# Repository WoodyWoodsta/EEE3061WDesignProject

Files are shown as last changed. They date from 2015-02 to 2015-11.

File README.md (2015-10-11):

# EEE3061W Mechatronics Design Project

Both single-thread and RTOS projects as well as other goodies for the biathletic robot as part of the Mechatronics Design project. 

*Includes:*
- 1st Semester C Project (Single thread)
- 2nd Semester C Project (FreeRTOS + CMSIS RTOS API + STM32Cube)
- All Altium Schematics and PCB Layouts
- Latex code for all reports

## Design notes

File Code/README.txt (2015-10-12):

The code included in this submission contains the following:

- "Team13 - 1stSemester.zip"
  - 1st semester code, single threaded, all main execution in main.c with calls to supporting libraries included.
  - Makes use of the Standard Peripheral Library supplied by ST Microelectronics

- "Team13 - 2ndSemester.zip"
  - 2nd semester code, multi-threaded, threads and queues are created in main.c as well as the kernel is fired in main()
  - Thread source is named "*_task.c"
  - Makes use of FreeRTOS V8.2.1, CMSIS RTOS API, CMSIS Hardware Abstraction Layer and originates from STM32CubeMX using their libraries

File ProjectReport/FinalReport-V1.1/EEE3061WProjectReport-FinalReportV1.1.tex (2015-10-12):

\input{woodamble}                                                       % Custom preamble
%----------------------------------------------------------------------------------------
% NAME AND CLASS SECTION
%----------------------------------------------------------------------------------------

\newcommand{\reportTitle}{Final Report} % Assignment title
\newcommand{\reportDueDate}{Wednesday,\ September\ 03,\ 2014}                    % Due date
\newcommand{\reportClass}{EEE3061W - Mechatronics Design}                               % Course/class
\newcommand{\reportClassTime}{10:30am}                                 % Class/lecture time
\newcommand{\reportClassInstructor}{Jones}                               % Teacher/lecturer
\newcommand{\reportAuthorName}{Team 13}                           % Your name
\newcommand{\reportDepartment}{Department of Electrical Engineering}           % Department

%----------------------------------------------------------------------------------------
% TITLE PAGE
%----------------------------------------------------------------------------------------

\title{
\begin{figure}[H]
  \begin{center}
    
  \end{center}
\end{figure}
\textmd{\Huge UNIVERSITY OF CAPE TOWN \\ \LARGE \reportDepartment} \\
\vspace{2in}
\textmd{\textbf{\LARGE \reportClass \\ \Huge Biathlon Robot \\ \reportTitle \\ \vspace{1.5in} \Large Team 13 \\  WDXSEA003 \textbar\space PRSSAM004 \textbar\space RJDYAR001 \textbar\space STRIBR001}}\\
}

\date{}

%========================================================================================
%========================================================================================

\begin{document}
  \maketitle
  \thispagestyle{empty}

\frontmatter
%----------------------------------------------------------------------------------------
% ABTRACT
%----------------------------------------------------------------------------------------
\setcounter{tocdepth}{3}                                                      % ToC Depth
\setcounter{secnumdepth}{2}                                     % Section Numbering Depth

\clearpage
\section*{Plaigiarism Declaration}
\addcontentsline{toc}{section}{Plaigiarism Declaration}
\label{sec:Plaigiarism Declaration}

\clearpage
\begin{figure}[H]
  \begin{center}
    
  \end{center}
\end{figure}

\begin{figure}[H]
  \begin{center}
    
  \end{center}
\end{figure}

\begin{abstract}
  \thispagestyle{empty}
  This report covers the post-design commentary and as-built designs of an autonomous bi-athletic robot for the EEE3061W Mechatronics Design Project 2015.  This robot was to partake in a sprint as well as launch a ping-pong ball after tracking a line and being aware of the end of the course. Most of the specifications were met and the robot performed the tasks that were set out at the beginning of the project.

\end{abstract}

%----------------------------------------------------------------------------------------
% TABLE OF CONTENTS
%----------------------------------------------------------------------------------------

\cleardoublepage
\addcontentsline{toc}{section}{Table of Contents}
\tableofcontents

\clearpage
\section*{List of Illustrations}
\addcontentsline{toc}{section}{List of Illustrations}
\label{sec:List of Illustrations}
\addcontentsline{toc}{subsection}{List of Figures}
\listoffigures
\clearpage

%----------------------------------------------------------------------------------------
% GLOSSARY
%----------------------------------------------------------------------------------------

%----------------------------------------------------------------------------------------
% INTRODUCTION
%----------------------------------------------------------------------------------------
\mainmatter
\clearpage
\section{Introduction}
\label{sec:Introduction}
  This report covers post-testing commentary and as-built designs for EEE3061W Mechatronics Design Project for 2015.  The project involved the design, manufacture and testing of a legged, autonomous, bi-athletic robot that was be able to partake in a 5m sprint, follow a line then throw a ping-pong ball.  The robot was to adhere to a set of specifications as provided by the course management. \\

  The entire project was split into two sections, each covering the semester's task.  The first section involved the sprinting aspect of the robot, and the second involved line following and launching.

  \subsection{Sprinter Introduction}
  \label{sub:Sprinter Introduction}
    In summary, the sprinting robot was to make use of a digital 3-axis gyroscope in an attempt to sprint 5m as fast as possible within a f ixed-width lane (maintain fixed heading).  The robot was also specified to start the sprint when the green light from a set of three lights was detected, signaling the beginning of the race. \\

    The locomotion design was constrained to the use of legs, making use of a mechanical linkage-type system to convert rotational motion from the provided motors into linear motion to move forward.  Other restrictions included the dimensions of the entire robot and out-of-pocket components budget.

  \subsection{Launcher Introduction}
  \label{sub:Launcher Introduction}
    The second stage of the project required the robot to first navigate along a line (autonomously) into a box and then throw a ping-pong ball as far as possible. The launching mechanism was limited to the use of a lever system, driven by a DC motor provided.  The rest of the restrictions follow from the Sprinter as well. \\

  The development of both robots followed the same design process whereby 3 conceptual designs were proposed and one final design (or a combination of ideas from more than one) was developed upon further after having drawn up a pros and cons comparison.  The final design was, at this stage, separated into the electronic and mechanical aspects.  As such, they are discussed separately.  Mechanical designs were modelled using SolidWorks and the electronic systems were drawn up in Altium Designer.

%----------------------------------------------------------------------------------------
% ELECTRICAL COMMENTARY
%----------------------------------------------------------------------------------------
\clearpage
\section{Electrical Commentary}
\label{sec:Electrical Commentary}
  Electrical systems for both semester's worth of design were on Printed Circuit Boards (PCBs), the first semester's PCBs being manufactured using the ``press-n-peel'' method and the second semester PCBs being manufactured professionally at Trax\footnote{Trax PCB Manufacture - \url{http://www.trax.co.za/}}. Both systems worked successfully after manufacture and minimal changes were made to the PCBs for the final demonstrations of the robot. Commentary on both systems and the associated software that was written for the systems can be found below.

  \subsection{Electrical System Design}
  \label{sub:Electrical System Design}
    \subsubsection{PCB Manufacturing Process}
    \label{subs:PCB Manufacturing Process}
      As stated, the PCBs manufactured for the first semester's robot were made using copper clad board and ``press-n-peel'' paper. This constrained the design of the boards since the manufacturing process was much more error prone. The track width minimum was increased greatly, decreasing the allowable complexity of the board layout thus increasing the overall size. Using this method also meant that the boards could not be double sided, further decreasing the complexity given the size.\\

      The second semester saw the PCBs manufactured professionally at Trax. This allowed a much smaller minimum track width and clearance limit (0.254mm) and could be manufactured double-sided with vias as well as a silk screen and solder mask. This gave the boards a much more professional feel, with easier assembly due to the silk screen and solder mask.

    \subsubsection{Power Supply Toplogy}
    \label{subs:Power Supply Toplogy}
      The addition of far more functionality in the second semester system meant the system drew a significantly larger amount of current excluding that of the motors. This saw the 12-5V regulation phase (LM317) dissipating a very large amount of heat, which is characteristic of linear voltage regulators operating at the level experienced. Use of a switched mode power supply would have reduced the power dissipation and minimised the need for a heat sink which took up an unnecessary amount of space on the final system.

    \subsubsection{Surface Mount Components}
    \label{subs:Surface Mount Components}
      The second semester system used surface mount forms of most of the passive electrical components in the system which had a huge impact on the final size of the boards. This was made possible by the professional manufacture process. The STM32F051C6 remained as a pluggable daughter board with two rows of headers. The STM32F0 could have been soldered directly to the main ControllerBoard which would have saved a lot of space, at least vertically.

  \subsection{Software Design}
  \label{sub:Software Design}
    \subsubsection{Software Structure}
    \label{subs:Software Structure}
      All software was written in C for the STM32F051C6. The software system written for the 1st semester robot was single-threaded and made use of a ``super-loop'' type layout, where initialisations were performed at the beginning and the main execution looped through in one loop with calls to various custom written libraries throughout. This suited the task as the level of complexity was not high, however, many parts of the super-loop became unused as the sequence progressed (such as checking for the green light).\\

      A more advanced method of scheduling was used in the second semester system to better suit the multi-functional nature of the newer system. The FreeRTOS\textsuperscript{\cite{freeRTOS}} kernel was implemented to bring to the system the ability to split the program into multiple threads (or tasks) which minimised the scheduling implications of a super-loop style program. Calls to the FreeRTOS source base were made using the CMSIS RTOS API specially written for the STM range of microcontrollers which worked well except for having to manually implement some unfinished feature inclusions in the API.\\

      The GitHub Repository used throughout the project can be found at \url{https://github.com/WoodyWoodsta/EEE3061WDesignProject/tree/master/Code}.

    \subsubsection{Control Methodology}
    \label{subs:Control Methodology}
      For both maintaining a fixed heading and line following, the control loop types were intended to be PID and this type of control was implemented fully in both software systems. However, in both cases, the system to control turned out to be too complex to model and thus only the proportional component of the control loops were used. This sufficed for both the straight line test as well as following a curved line with the sensors.

%----------------------------------------------------------------------------------------
% MECHANICAL COMMENTARY
%----------------------------------------------------------------------------------------
\clearpage
\section{Mechanical Commentary}
\label{sec:Mechanical Commentary}
The mechanical design consisted mainly of the leg mechanism attached to a generic base and later a launcher was added to the center. The mechanism chosen for the legs was based off a Klann linkage\textsuperscript{\cite{klannLinkage}} which is common amongst walking robots. The mechanism converts rotary motion to linear motion which replicates moving legs. The primary difficulty with this mechanism was the non-fluid motion of the Klann linkage design. With regards to the first semester design, these limitations meant high stress concentrations were created at critical points within the linkage. As a result, the central leg linkage was fractured during testing. Other complications with the design centered on the high friction generated between moving parts. This was partly due to the choice of material but mostly as a result of the small scale of the robot relative to the external and internal forces generated.\\

Apart from this, the rest of the robot functioned relatively well from the first iteration. The calculated gear ratio was accurate because the required torque needed to overcome the weight of the robot was reached from the first design.\\

\subsection{Linkage Size and Strength}
\label{sub:Linkage Size and Strength}
  From the post design work it was apparent that the linkage size, particularly around the interfaces with other links was insufficient in the first design. We also learnt that having moving parts made of Perspex in direct contact with each other was conducive to high friction generation. As well as this, despite the gears functioning appropriately, there was significant difficulty in locating the gears. In the first design, Perspex was attached using epoxy perpendicularly to the Perspex base. This interface had to be reattached multiple times as the material used was not ideal for epoxy attachments.\\

  To address the main problem of linkage fracture, the size of each linkage interface as well as the linkages themselves was increased. This was done to rectify any stress concentrations that may have developed during usage due to misalignment. Additionally, the carbon fiber rods were replaced with standard nuts and bolts in all shaft requirements. The friction generated within linkages due to the carbon fiber rods resulted in the degradation of the holes within linkages which contributed significantly to the misalignment problem. To further alleviate this problem, brass bushings were placed in every hole within the Perspex. To assist with the gear location, hex shaped holes were cut into the Perspex and a hex nut was force fit into it. This allowed the gear to be threaded onto the bar easily, and could be kept in place using lock nuts. Between each of the linkages, a stationary Perspex spacer was placed to prevent direct contact between them. This not only significantly reduced the friction but also assisted in maintaining linkage alignment.\\

\subsection{Body Size}
\label{sub:Body Size}
  The overall size of the robot was increased to accommodate the launcher mechanism. This was necessary to ensure optimal functionality and performance of both the launcher and the leg mechanism. Worm gears were included in the leg mechanism due to the increased weight of the robot and therefore the increased need for more torque. The compromise was that the overall speed of the robot was heavily sacrificed.

%----------------------------------------------------------------------------------------
% RESULTS AND CONCLUSIONS
%----------------------------------------------------------------------------------------
\clearpage
\section{Results and Conclusions}
\label{sec:Results and Conclusions}
  \subsection{Sprinter Results}
  \label{sub:Sprinter Results}
    The robot built for the 1st semester demonstration was able to remain within the demarcated track width autonomously and do so at a reasonable pace. The robot successfully completed the race after sensing the green light in variable ambient conditions.\\

    Apart from a fractured leg that occurred during the demonstrations, the robot was able to continue to perform.

  \subsection{Launcher Results}
  \label{sub:Launcher Results}
    The robot built for the 2nd semester demonstration was able to start following the line after the light was sensed and the line following was very successful. It achieved this autonomously and was able to sense the box marking on the floor and move into the box. The robot was then able to throw the ping pong ball after reaching the edge of the box to complete the task.

%----------------------------------------------------------------------------------------
% BIBLIOGRAPHY
%----------------------------------------------------------------------------------------
\clearpage
% \nocite{*}
\printbibliography

%----------------------------------------------------------------------------------------
% APPENDICES
%----------------------------------------------------------------------------------------
\section{APPENDIX A: Final Electrical Schematics}
\label{sec:APPENDIX A: Final Electrical Schematics}
  \subsection{1st Semester Electrical Schematics}
  \label{sub:1st Semester Electrical Schematics}

    \begin{figure}[H]
      \begin{center}
        \makebox[\textwidth][c]{}
        \caption{Schematic of the PowerBoard in the 1st Semester Electrical System}
        \label{fig:PowerBoardSchematic}
      \end{center}
    \end{figure}

    \begin{figure}[H]
      \begin{center}
        \makebox[\textwidth][c]{}
        \caption{Schematic of the ControllerBoard in the 1st Semester Electrical System}
        \label{fig:ControllerBoardSchematic}
      \end{center}
    \end{figure}

  \subsection{2nd Semester Electrical Schematics}
  \label{sub:2nd Semester Electrical Schematics}

    \begin{figure}[H]
      \begin{center}
        \makebox[\textwidth][c]{}
        \caption{Schematic of the PowerBoard in the 2nd Semester Electrical System}
        \label{fig:PowerBoardSchematicV2}
      \end{center}
    \end{figure}

    \begin{figure}[H]
      \begin{center}
        \makebox[\textwidth][c]{}
        \caption{Schematic of the ControllerBoard in the 2nd Semester Electrical System}
        \label{fig:ControllerBoardV2Schematic}
      \end{center}
    \end{figure}

    \begin{figure}[H]
      \begin{center}
        \makebox[\textwidth][c]{}
        \caption{Schematic of the SensorBoard in the 2nd Semester Electrical System}
        \label{fig:LineSensorBoardSchematic}
      \end{center}
    \end{figure}

    \begin{figure}[H]
      \begin{center}
        
        \caption{Schematic of the SensorModule in the 2nd Semester Electrical System}
        \label{fig:LineSensorModuleSchematic}
      \end{center}
    \end{figure}

\clearpage
\section{APPENDIX B: Final Electrical PCB Designs}
\label{sec:APPENDIX B: Final Electrical PCB Designs}
  \subsection{1st Semester Electrical PCB Designs}
  \label{sub:1st Semester Electrical PCB Designs}

    \begin{figure}[H]
      \begin{center}
        \makebox[\textwidth][c]{}
        \caption{PCB Layout of the PowerBoard in the 1st Semester Electrical System}
        \label{fig:PowerBoardPCBRev1}
      \end{center}
    \end{figure}

    \begin{figure}[H]
      \begin{center}
        \makebox[\textwidth][c]{}
        \caption{PCB Layout of the ControllerBoard in the 1st Semester Electrical System}
        \label{fig:ControllerBoardPCB}
      \end{center}
    \end{figure}

  \subsection{2nd Semester Electrical PCB Designs}
  \label{sub:2nd Semester Electrical PCB Designs}

    \begin{figure}[H]
      \begin{center}
        \makebox[\textwidth][c]{}
        \caption{PCB Layout of the PowerBoard in the 2nd Semester Electrical System}
        \label{fig:PowerBoardPCBV2}
      \end{center}
    \end{figure}

    \begin{figure}[H]
      \begin{center}
        \makebox[\textwidth][c]{}
        \caption{PCB Layout of the ControllerBoard in the 2nd Semester Electrical System}
        \label{fig:ControllerBoardV2PCB}
      \end{center}
    \end{figure}

    \begin{figure}[H]
      \begin{center}
        \makebox[\textwidth][c]{}
        \caption{PCB Layout of the SensorBoard in the 2nd Semester Electrical System}
        \label{fig:LineSensorBoardPCBRev2}
      \end{center}
    \end{figure}

    \begin{figure}[H]
      \begin{center}
        \makebox[\textwidth][c]{}
        \caption{PCB Layout of the SensorModule in the 2nd Semester Electrical System}
        \label{fig:SensorModulePCB}
      \end{center}
    \end{figure}

\clearpage
\section{APPENDIX C: Final Mechanical Drawings}
\label{sec:APPENDIX C: Final Mechanical Drawings}

\end{document}
%----------------------------------------------------------------------------------------
% INSTRUCTIONS AND TEMPLATE COMPONENTS
%----------------------------------------------------------------------------------------

% Set space - \vspace{length}
% Horizontal line - \hrule
% Pagebreak - \clearpage or \newpage - they seem to do the same thing

% Normal equation:
% \begin{equation}
%   p = \frac{p_g - k}{m}
% \end{equation}

% Aligned equation:
% \begin{equation}
%   \begin{split}
%     \rho_5  & = -\frac{\left(1575-1900\right)}{g\left(105\e{-3}-70\e{-3}\right)}\\
%             & = 946.56 \text{ kg/m\(^{-3}\)}\\
%     \rho_6  & = -\frac{\left(1900-2150\right)}{g\left(70\e{-3}-42\e{-3}\right)}\\
%             & = 910.15 \text{ kg/m\(^{-3}\)}\\
%   \end{split}
% \end{equation}

% Table: Can get from the table site!
% \begin{table}[h]
% \centering
% \begin{tabular}{cccc}
% \multicolumn{4}{c}{\cellcolor[HTML]{EFEFEF}DATA MEASUREMENTS} \\ \hline
% \multicolumn{1}{c|}{\begin{tabular}[c]{@{}c@{}}Known Weight \\ Pressure (Psi)\end{tabular}} & \multicolumn{1}{c|}{\begin{tabular}[c]{@{}c@{}}Known Weight\\ Pressure (Bar)\end{tabular}} & \multicolumn{1}{c|}{\begin{tabular}[c]{@{}c@{}}Gauge Pressure\\ (Psi)\end{tabular}} & \begin{tabular}[c]{@{}c@{}}Gauge Pressure\\ (Bar)\end{tabular} \\ \hline
% \multicolumn{1}{c|}{22} & \multicolumn{1}{c|}{1.52} & \multicolumn{1}{c|}{9.43} & 0.65 \\
% \multicolumn{1}{c|}{\textbf{27}} & \multicolumn{1}{c|}{\textbf{1.86}} & \multicolumn{1}{c|}{\textbf{13.78}} & \textbf{0.95} \\
% \multicolumn{1}{c|}{32} & \multicolumn{1}{c|}{2.21} & \multicolumn{1}{c|}{17.40} & 1.20 \\
% \multicolumn{1}{c|}{37} & \multicolumn{1}{c|}{2.55} & \multicolumn{1}{c|}{21.76} & 1.50 \\
% \multicolumn{1}{c|}{42} & \multicolumn{1}{c|}{2.90} & \multicolumn{1}{c|}{26.11} & 1.80 \\
% \multicolumn{1}{c|}{47} & \multicolumn{1}{c|}{3.24} & \multicolumn{1}{c|}{29.01} & 2.00 \\
% \multicolumn{1}{c|}{\textbf{52}} & \multicolumn{1}{c|}{\textbf{3.59}} & \multicolumn{1}{c|}{\textbf{33.36}} & \textbf{2.30} \\
% \multicolumn{1}{c|}{57} & \multicolumn{1}{c|}{3.93} & \multicolumn{1}{c|}{37.71} & 2.60 \\ \hline
% \end{tabular}
% \caption{Dead weight tester and gauge measurements}
% \label{gaugeMeasurements}
% \end{table}

% Picture:
% \begin{figure}[H]
%   \begin{center}
%     \includegraphics[width=0.4\columnwidth]{MEC2022SLab1Exp1}
%     \caption{Apparatus}
%     \label{liquidDiagram}
%   \end{center}
% \end{figure}

% Graph:
% \begin{figure}[H]
%   \centering
%   \begin{tikzpicture}
%     \begin{axis}[
%       xlabel=Known Weight (Psi),
%       ylabel=Reading (Psi),
%       grid=major]
%     \addplot[color=red, smooth] coordinates {
%       (22,9.43)
%       (27,13.78)
%     };
%     \addlegendentry{Gauge}

%     \addplot[color=blue, dashed, smooth] coordinates {
%       (22,22)
%       (27,27)
%     };
%     \addlegendentry{Known weight}

%     \end{axis}
%   \end{tikzpicture}
%   \caption{Dead weight tester and gauge measurements}
%   \label{gaugePlot}
% \end{figure}

% Indented Text: (bit of a hacky way to do it)
% \begin{quote}
% where \(p_g\) is the gauge reading, \(m\) is the error coefficient, \(p\) is the known (``correct'') pressure and \(k\) is the error constant
% \end{quote}

% Code Snippet:
% \begin{minted}{c}
%   void main(void) {
%     init_leds();
%
%     while (TRUE) {
%       __asm("nop");
%     }
%   }
% \end{minted}

% Bibliography:
% \begin{thebibliography}{99}
%   \bibitem{itemname}
%   Author,
%   Date.
%   \emph{Title}.
%   Edition.
%   Press.
%   \url{http://web.iitd.ac.in/~shouri/eel201/tuts/diode_switch.pdf}
% \end{thebibliography}

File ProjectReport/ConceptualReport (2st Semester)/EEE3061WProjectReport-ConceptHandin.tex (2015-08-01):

\input{woodamble}                                                       % Custom preamble
%----------------------------------------------------------------------------------------
% NAME AND CLASS SECTION
%----------------------------------------------------------------------------------------

\newcommand{\hmwkTitle}{Conceptual Design Report} % Assignment title
\newcommand{\hmwkDueDate}{Wednesday,\ September\ 03,\ 2014}                    % Due date
\newcommand{\hmwkClass}{EEE3061W - Mechatronics Design}                    % Course/class
\newcommand{\hmwkClassTime}{10:30am}                                 % Class/lecture time
\newcommand{\hmwkClassInstructor}{Jones}                               % Teacher/lecturer
\newcommand{\hmwkAuthorName}{Team 13}    % Your name
\newcommand{\hmwkDepartment}{Department of Electrical Engineering}           % Department

%----------------------------------------------------------------------------------------
% TITLE PAGE
%----------------------------------------------------------------------------------------

\title{
\begin{figure}[H]
  \begin{center}
    
  \end{center}
\end{figure}
\textmd{\Huge UNIVERSITY OF CAPETOWN \\ \LARGE \hmwkDepartment} \\
\vspace{2in}
\textmd{\textbf{\LARGE \hmwkClass \\ \Huge Biathlon Robot \\ \hmwkTitle \\ \vspace{1.5in} \Large Team 13 \\  WDXSEA003 \textbar\space PRSSAM004 \textbar\space RJDYAR001 \textbar\space STRIBR001}}\\
%\normalsize\vspace{0.1in}\small{Due\ on\ \hmwkDueDate}\\
%\vspace{0.1in}\large{\textit{\hmwkClassInstructor\ \hmwkClassTime}}
}

\date{}

%========================================================================================
%========================================================================================

\begin{document}

\maketitle
\clearpage

%----------------------------------------------------------------------------------------
% ABTRACT
%----------------------------------------------------------------------------------------
\setcounter{tocdepth}{2}                                                      % ToC Depth

% \begin{abstract}
% This preliminary report covers the conceptual design stage of the EEE3061W Mechatronics Design 2015 project involving the design and manufacture of a bi-athletic robot.  This robot is to partake in a sprint as well as throw a weighted ping-pong ball.

% \end{abstract}
% \newpage

%----------------------------------------------------------------------------------------
% TABLE OF CONTENTS
%----------------------------------------------------------------------------------------

% \clearpage

% \tableofcontents

% \clearpage

% \listoffigures
% \listoftables

% \clearpage

% %----------------------------------------------------------------------------------------
% % NOMENCLATURE
% %----------------------------------------------------------------------------------------

% \begin{homeworkProblem}[{Nomenclature}]
% \textbf{Constants}

% \(V_{LINE}\) - Nominal Line Voltage\\
% \(A_v\) - Operational Amplifier Gain\\
% \(db_{SPL}\) - Sound Pressure Level\\
% \(\theta_S\) - Phase Shift

% \end{homeworkProblem}

%----------------------------------------------------------------------------------------
% INTRODUCTION
%----------------------------------------------------------------------------------------
\begin{homeworkProblem}[{Introduction}]
This preliminary report and reports hereafter together cover the complete design process for EEE3061W Mechatronics Design Project for 2015.  The project involves the design, manufacture and testing of a legged, autonomous, bi-athletic robot that will be able to partake in a 5m sprint and then throw a weighted ping-pong ball.  The robot is to adhere to a set of specifications as provided by the course management. \\

The following report details the concepts and designs for the second stage of the project, namely the shotput challenge. In this stage, the primary requirements are for the robot to launch a ping pong ball as perpendicularly far as possible. The launcher should be attached to the same robot as the previous project. As well as this, the launcher should be self-reloadable and utilise the power of the given DC motor to achieve launching.

\begin{homeworkSection}{Aim}
To assess and compare conceptual designs of robot launchers and conclude which is the most feasible and viable for this application.
\end{homeworkSection}

\begin{homeworkSection}{Method}
  \begin{itemize}
    \item Generate designs
    \item Detail and explain each concept
    \item Compare and contrast each design
    \item Decide on a final concept design
    \item Generate conclusions based on the chosen design
  \end{itemize}
\end{homeworkSection}
\end{homeworkProblem}

%----------------------------------------------------------------------------------------
% DESIGN CONCEPTS
%----------------------------------------------------------------------------------------
\begin{homeworkProblem}[{Design Concepts}]
\begin{homeworkSection}{Design Concept 1}
  \begin{figure}[H]
    \begin{center}
      
      \caption{3D Render of Design Concept 1}
      \label{concept1}
    \end{center}
  \end{figure}

The first design is clearly based on a standard catapult. This is the first concept chosen as it is the simplest and most common design. The function of the catapult is based loosely on a mousetrap and employs the same general idea of the trap's spring loaded release mechanism. The difference is that there is a stopper mid-way through the movement of the catapult arm which allows for a short impulse time during the release of the ping pong ball. For the reload mechanism, the motor is used to wind back the catapult arm until it hits a mechanical latch. This is achieved by the use of a high step down gearbox to generate enough torque in order to extend the springs. Once the the catapult is in position and the ball is placed on the launcher, the mechanical latch will then be released electronically which will then activate the catapult mechanism. \\

Another possibility, which can be applied to all the subsequent designs in addition to this one, is to have the reload mechanism only activate once the ball is in the holder. This removes the need to have time delay between the reload and launch sequence, and reduces the overall amount of mechanisms and moving parts. This vould be achieved by using a light sensor to sense when the ball is in holder while it is in the upright position.
\end{homeworkSection}

\begin{homeworkSection}{Design Concept 2}
  \begin{figure}[H]
    \begin{center}
      
      \caption{3D Render of Design Concept 2}
      \label{concept2}
    \end{center}
  \end{figure}

For this concept, a similar mechanism is used as in the previous one, but instead of a catapult - type launcher, it utilises a more direct “hit” impact on the ball. this is more in line with the nature of springy ping pong balls' projection. Similar to the previous concept, the lever arm is pulled back by using the motor and a series of gears. This is again held in place by a mechanical latch and is released again once a light sensor is triggered within the tube holder. The ball sits in the holder with approximately half of the ball jutting out where the paddle will hit the ball. The impact allows for a very short impulse time and a fast projection of the ping pong ball.

\end{homeworkSection}

\begin{homeworkSection}{Design Concept 3}
  \begin{figure}[H]
    \begin{center}
      
      \caption{3D Render of Design Concept 3}
      \label{concept3}
    \end{center}
  \end{figure}

  The third and final concept design is based on a ballista/crossbow design. This allows for a potentially more stable arrangement as the only moving parts are the spring devices or elastic cables. this means there are no rigid components that have to move, which will reduce any uncertainty. The basic design uses a winch that pulls back the elastic band using the motor. A similar latch system is then used which will ultimately launch the ping pong ball. The motor ultimately engages and disengages the the latch and a light sensor will again detect the ball and trigger the motor to disengage the latch.

\end{homeworkSection}
\end{homeworkProblem}

\clearpage

\begin{homeworkProblem}[{Final Concept}]
\begin{table}[H]
\centering
\caption{Design Concept Comparison Table}
\label{comparisonTable}
\begin{tabular}{@{}cccccc@{}}
\toprule
\multicolumn{2}{c}{{\bf Design 1}} & \multicolumn{2}{c}{{\bf Design 2}} & \multicolumn{2}{c}{{\bf Design 3}} \\ \midrule
{\bf Pros} & {\bf Cons} & {\bf Pros} & {\bf Cons} & {\bf Pros} & {\bf Cons} \\
\begin{tabular}[c]{@{}c@{}}Simplest \\ mechanism\end{tabular} & \begin{tabular}[c]{@{}c@{}}May not be \\ suitable for \\ this projectile\end{tabular} & \begin{tabular}[c]{@{}c@{}}Relatively\\ simple\\ mechanism\end{tabular} & \begin{tabular}[c]{@{}c@{}}Difficult to\\ control\end{tabular} & \begin{tabular}[c]{@{}c@{}}Most stable\\ design\end{tabular} & \begin{tabular}[c]{@{}c@{}}May not be\\ suitable for this\\ projectile\end{tabular} \\
\begin{tabular}[c]{@{}c@{}}Ease of\\ assembly\end{tabular} & \begin{tabular}[c]{@{}c@{}}Relatively\\ large\end{tabular} & \begin{tabular}[c]{@{}c@{}}Ease of\\ assembly\end{tabular} & \begin{tabular}[c]{@{}c@{}}Relatively\\ large\end{tabular} & \begin{tabular}[c]{@{}c@{}}Smallest\\ in size\end{tabular} & \begin{tabular}[c]{@{}c@{}}Difficult to\\ assemble\end{tabular} \\
\begin{tabular}[c]{@{}c@{}}Uses\\ standard\\ parts\end{tabular} & \begin{tabular}[c]{@{}c@{}}Could\\ damage robot\\ due to sudden\\ stopping\end{tabular} & \begin{tabular}[c]{@{}c@{}}Uses\\ standard\\ parts\end{tabular} & \begin{tabular}[c]{@{}c@{}}Could damage\\ robot due to\\ impact stopping\end{tabular} & \begin{tabular}[c]{@{}c@{}}Sudden impact\\ would not\\ affect robot\end{tabular} & \begin{tabular}[c]{@{}c@{}}Some parts\\ may be\\ difficult to\\ create\end{tabular} \\ \bottomrule
\end{tabular}
\end{table}

After considering the above table and other factors, Design concept 2 was chosen as the final concept. The deciding factor was that for a ball of this size, weight and springy nature, a sudden impact or hit imparted on the ball would be able to project the ball the furthest distance.

\begin{homeworkSection}{Other Design Considerations and Potential Improvements}

Although the current chosen design is simple, adding some degree of complexity could improve the overall performance. In particular, the use of a solenoid instead of a mechanical release would make the launch far more consistent and easier to time and predict (however, this is not a possibility due to project criteria and restrictions). \\

From the above SolidWorks models, there is much to improve on in terms of sizing. These steps however can be taken further down the iterative optimisation path. The choice of material may also change as more convenient and less costly options are possibly discovered.
\end{homeworkSection}

\end{homeworkProblem}

%----------------------------------------------------------------------------------------
% PRELIMINARY CALCULATIONS
%----------------------------------------------------------------------------------------
\begin{homeworkProblem}[{Preliminary Calculations}]
  \begin{table}[H]
\centering
\caption{Table of Constants}
\label{constantsTable}
\begin{tabular}{|l|l|}
\hline
Coefficient of restitution (\(e\)) & 0.90                \\ \hline
Mass of table tennis ball (\(m_1\))  & 2.7 g               \\ \hline
Voltage of motor (\(V\))           & 12 V                \\ \hline
Current of motor (\(A\))           & 0.1 A               \\ \hline
Angle of launch (\(\theta\))            & 45 degrees          \\ \hline
Drag coefficient (\(Cd\))           & 0.5                 \\ \hline
Density of air (\(\rho\))             & 1.274 kg/m\(^3\) \\ \hline
Diameter of ball (\(d\))           & 40 mm               \\ \hline
Mass of lever arm (\(m_2\))          & 17 g                \\ \hline
Spring constant (\(k\))               & 3.45 N              \\ \hline
Lever arm length (\(L\))           & 100 mm              \\ \hline
\end{tabular}
\end{table}

\textbf{Assumptions Made:}
\begin{itemize}
  \item From extensive research the torque required to put a mousetrap spring down by 60 degrees is 0.212 Nm.
  \item The height of the robot is ignored in distance calculations as it is only 150 mm of the ground.
\end{itemize}

\textbf{Torque Required:}
\begin{equation}
  \begin{split}
    T &= 0.212 \text{Nm}\\
    P &= VI = (12)(0.1)\\
    P &= 1.2 \text{W}\\
    P &= \omega T\\
    \omega &= \frac{P}{T}\\
    \omega &= 5.66 \text{ rad}^{-1}\\
    \omega &= 612.61 \text{ rad}^{-1} \text{Output from motor at 12 V}\\
    \text{motor step} &= \frac{612.61}{5.66} = 108
  \end{split}
\end{equation}

This step can be achieved using a worm gear combined with a gear train.\\

\textbf{Speed of ping pong ball:}

Energy conservation:

\begin{equation}
  U = V + E_k + E_p
\end{equation}

\begin{equation}
  \frac{k\theta^2}{2} = \frac{I\omega^2}{2} + \frac{m(\omega r)^2}{2} + mgh
\end{equation}
\begin{equation}
  \frac{3.45(1.04)^2}{2} = \frac{(1.67 \e{-9})\omega^2}{2} + \frac{0.017(\omega \times 0.1)^2}{2} + 0.017(9.81)(0.1)
\end{equation}
\begin{equation}
  1.89 - 0.0167 = 8.87 \e{-5} \omega^2
\end{equation}
\begin{equation}
  \omega = 145.36 \text{ rad}^{-1}
\end{equation}
\begin{equation}
  v = \omega r = 14.5 \text{m/s}^{-1}
\end{equation}
\begin{equation}
  e m_1 v_1 = m_2 v_2
\end{equation}
\begin{equation}
  v_2 = \frac{17}{2.7} \times 14.5 \times 0.90
\end{equation}
\begin{equation}
  v_2 = 85.77 \text{m/s}^{-1}
\end{equation}

From dynamic calculations, given the launch angle and using an online ping pong ball calculator, the distance found was \textbf{21.4368 m}.

\begin{figure}[H]
  \begin{center}
    
    \caption{Ball Speed Calculator}
    \label{ballspeed}
  \end{center}
\end{figure}

\end{homeworkProblem}

\end{document}
%----------------------------------------------------------------------------------------
% INSTRUCTIONS AND TEMPLATE COMPONENTS
%----------------------------------------------------------------------------------------

% Document is structured in --> [document]
%                                 [homeworkProblem]
%                                   [homeworkSection]
%                                     [COMPONENTS]

% Set space - \vspace{length}
% Horizontal line - \hrule
% Pagebreak - \clearpage or \newpage - they seem to do the same thing

% Normal equation:
% \begin{equation}
%   p = \frac{p_g - k}{m}
% \end{equation}

% Aligned equation:
% \begin{equation}
%   \begin{split}
%     \rho_5  & = -\frac{\left(1575-1900\right)}{g\left(105\e{-3}-70\e{-3}\right)}\\
%             & = 946.56 \text{ kg/m\(^{-3}\)}\\
%     \rho_6  & = -\frac{\left(1900-2150\right)}{g\left(70\e{-3}-42\e{-3}\right)}\\
%             & = 910.15 \text{ kg/m\(^{-3}\)}\\
%   \end{split}
% \end{equation}

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

% Picture:
% \begin{figure}[H]
%   \begin{center}
%     \includegraphics[width=0.4\columnwidth]{MEC2022SLab1Exp1}
%     \caption{Apparatus}
%     \label{liquidDiagram}
%   \end{center}
% \end{figure}

% Graph:
% \begin{figure}[H]
%   \centering
%   \begin{tikzpicture}
%     \begin{axis}[
%       xlabel=Known Weight (Psi),
%       ylabel=Reading (Psi),
%       grid=major]
%     \addplot[color=red, smooth] coordinates {
%       (22,9.43)
%       (27,13.78)
%     };
%     \addlegendentry{Gauge}

%     \addplot[color=blue, dashed, smooth] coordinates {
%       (22,22)
%       (27,27)
%     };
%     \addlegendentry{Known weight}

%     \end{axis}
%   \end{tikzpicture}
%   \caption{Dead weight tester and gauge measurements}
%   \label{gaugePlot}
% \end{figure}

% Indented Text: (bit of a hacky way to do it)
% \begin{quote}
% where \(p_g\) is the gauge reading, \(m\) is the error coefficient, \(p\) is the known (``correct'') pressure and \(k\) is the error constant
% \end{quote}

% Code Snippet:
% \begin{lstlisting}
% .model AKM02 D(Is=1.5n Rs=.5 Cjo=80p M=0.3 Vj=1 nbv=3 bv=6.2 Ibv=1m Vpk=6.2 mfg=OnSemi type=zener)
% \end{lstlisting}

% Bibliography:
% \begin{thebibliography}{99}
%   \bibitem{itemname}
%   Author,
%   Date.
%   \emph{Title}.
%   Edition.
%   Press.
%   \url{http://web.iitd.ac.in/~shouri/eel201/tuts/diode_switch.pdf}
% \end{thebibliography}

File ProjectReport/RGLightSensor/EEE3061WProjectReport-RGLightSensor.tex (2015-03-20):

\input{woodamble}                                                       % Custom preamble
%----------------------------------------------------------------------------------------
% NAME AND CLASS SECTION
%----------------------------------------------------------------------------------------

\newcommand{\hmwkTitle}{RG Light Sensor Report} % Assignment title
\newcommand{\hmwkDueDate}{Wednesday,\ September\ 03,\ 2014}                    % Due date
\newcommand{\hmwkClass}{EEE3061W - Mechatronics Design}                    % Course/class
\newcommand{\hmwkClassTime}{10:30am}                                 % Class/lecture time
\newcommand{\hmwkClassInstructor}{Jones}                               % Teacher/lecturer
\newcommand{\hmwkAuthorName}{Team 13}    % Your name
\newcommand{\hmwkDepartment}{Department of Electrical Engineering}           % Department

%----------------------------------------------------------------------------------------
% TITLE PAGE
%----------------------------------------------------------------------------------------

\title{
\begin{figure}[H]
  \begin{center}
    
  \end{center}
\end{figure}
\textmd{\Huge UNIVERSITY OF CAPETOWN \\ \LARGE \hmwkDepartment} \\
\vspace{2in}
\textmd{\textbf{\LARGE \hmwkClass \\ \Huge Biathlon Robot \\ \hmwkTitle \\ \vspace{1.5in} \Large Team 13 \\  WDXSEA003 \textbar\space PRSSAM004 \textbar\space RJDYAR001 \textbar\space STRIBR001}}\\
%\normalsize\vspace{0.1in}\small{Due\ on\ \hmwkDueDate}\\
%\vspace{0.1in}\large{\textit{\hmwkClassInstructor\ \hmwkClassTime}}
}

\date{}

%========================================================================================
%========================================================================================

\begin{document}

\maketitle
\clearpage

%----------------------------------------------------------------------------------------
% ABTRACT
%----------------------------------------------------------------------------------------
\setcounter{tocdepth}{2}                                                      % ToC Depth

% \begin{abstract}
% This preliminary report covers the conceptual design stage of the EEE3061W Mechatronics Design 2015 project involving the design and manufacture of a bi-athletic robot.  This robot is to partake in a sprint as well as throw a weighted ping-pong ball.

% \end{abstract}
% \newpage

%----------------------------------------------------------------------------------------
% TABLE OF CONTENTS
%----------------------------------------------------------------------------------------

% \clearpage

% \tableofcontents

% \clearpage

% \listoffigures
% \listoftables

% \clearpage

%----------------------------------------------------------------------------------------
% NOMENCLATURE
%----------------------------------------------------------------------------------------

%----------------------------------------------------------------------------------------
% INTRODUCTION
%----------------------------------------------------------------------------------------
\begin{homeworkProblem}[{Introduction}]
This report covers the design and build of an Red\(\slash\)Green Light Detecting Sensor (hereafter referred to as RG Sensor) as part of the EEE3061W Mechatronics Design Project involving the building of a biathletic robot.
\end{homeworkProblem}

%----------------------------------------------------------------------------------------
% CIRCUIT DIAGRAM
%----------------------------------------------------------------------------------------
\begin{homeworkProblem}[Circuit Diagram]
Figure \ref{schematic1} shows the complete circuit diagram for the light sensor including the sensing, ambient sensing, indication and digital output portions of the circuit.

\begin{figure}[H]
  \begin{center}
    
    \caption{Complete circuit diagram of the RG Light Sensor}
    \label{schematic1}
  \end{center}
\end{figure}

\end{homeworkProblem}

%----------------------------------------------------------------------------------------
% CIRCUIT DIAGRAM
%----------------------------------------------------------------------------------------
\begin{homeworkProblem}[Brief Explanation and Calculations]
The team took on a slightly unorthodox approach to sensing the different coloured sources of light in that the sensing is performed by LEDs themselves.  The LM358N is set up in a comparator configuration, one for sensing red light and the other for sensing green light.  Another addition made was the use of same types of LEDs as secondary sensors to sense the ambient light intensity in the immediate environment.  These provide a reference voltage level which, theoretically speaking, will be accurate in any environment with respect to the ambient light levels.  Apart from this ability to adapt, having the LEDs provide the voltage for the reference level for the comparator meant the sensor does not draw any current to do so.  The entire passive element of the sensing portion of the circuit is not connected to the source and hence draws nothing from it.  This is very well aligned with the power consumption design goal.  Unfortunately, the red LED picked up light from the green source, due to the fact that the source is not exactly green.  This meant that a ``small'' amount of combinational logic had to be implemented to result in the correct outputs.\\

The voltage outputs from the sensing LEDs (both for ambient and actual light) were scaled using resistor dividers which were calculated so as to get accurate results from the comparator.  Table 1 shows the voltage levels from the sensors acquired through the tests.\\

\begin{table}[h]
\centering
\label{data}
\begin{tabular}{c|c|c|c|c|c|c|}
\cline{2-7}
                           & \multicolumn{3}{c|}{\cellcolor[HTML]{EFEFEF}{\color[HTML]{000000} RED SENSOR (mV)}} & \multicolumn{3}{c|}{\cellcolor[HTML]{EFEFEF}{\color[HTML]{000000} GREEN SENSOR (mV)}} \\ \cline{2-7} 
                           & Off (Ambient)               & Red Source               & Green Source               & Off (Ambient)                & Red Source                & Green Source               \\ \hline
\multicolumn{1}{|c|}{20cm} & 10                          & 910                      & 800                        & 6                            & 7                         & 300                        \\ \hline
\multicolumn{1}{|c|}{30cm} & 10                          & 700                      & 770                        & 6                            & 7                         & 230                        \\ \hline
\end{tabular}
\caption{Table showing results from sensor tests}

\end{table}

The above values were used to calculate the correct ratios to divide the output of the sensing LEDs for the opamp.\\

A 3.3V Linear Voltage Regulator was used to provide a rail for the switching components which provide the digital outputs.  All switching and combinational logic was implemeted using BC550 NPN transistors.

\end{homeworkProblem}

%----------------------------------------------------------------------------------------
% BOM
%----------------------------------------------------------------------------------------
\begin{homeworkProblem}[Bill of Materials]
The next page shows a bill of materials for the above design.

\end{homeworkProblem}
\end{document}
%----------------------------------------------------------------------------------------
% INSTRUCTIONS AND TEMPLATE COMPONENTS
%----------------------------------------------------------------------------------------

% Document is structured in --> [document]
%                                 [homeworkProblem]
%                                   [homeworkSection]
%                                     [COMPONENTS]

% Set space - \vspace{length}
% Horizontal line - \hrule
% Pagebreak - \clearpage or \newpage - they seem to do the same thing

% Normal equation:
% \begin{equation}
%   p = \frac{p_g - k}{m}
% \end{equation}

% Aligned equation:
% \begin{equation}
%   \begin{split}
%     \rho_5  & = -\frac{\left(1575-1900\right)}{g\left(105\e{-3}-70\e{-3}\right)}\\
%             & = 946.56 \text{ kg/m\(^{-3}\)}\\
%     \rho_6  & = -\frac{\left(1900-2150\right)}{g\left(70\e{-3}-42\e{-3}\right)}\\
%             & = 910.15 \text{ kg/m\(^{-3}\)}\\
%   \end{split}
% \end{equation}

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

% Picture:
% \begin{figure}[H]
%   \begin{center}
%     \includegraphics[width=0.4\columnwidth]{MEC2022SLab1Exp1}
%     \caption{Apparatus}
%     \label{liquidDiagram}
%   \end{center}
% \end{figure}

% Graph:
% \begin{figure}[H]
%   \centering
%   \begin{tikzpicture}
%     \begin{axis}[
%       xlabel=Known Weight (Psi),
%       ylabel=Reading (Psi),
%       grid=major]
%     \addplot[color=red, smooth] coordinates {
%       (22,9.43)
%       (27,13.78)
%     };
%     \addlegendentry{Gauge}
    
%     \addplot[color=blue, dashed, smooth] coordinates {
%       (22,22)
%       (27,27)
%     };
%     \addlegendentry{Known weight}
    
%     \end{axis}
%   \end{tikzpicture}
%   \caption{Dead weight tester and gauge measurements}
%   \label{gaugePlot}
% \end{figure}

% Indented Text: (bit of a hacky way to do it)
% \begin{quote}
% where \(p_g\) is the gauge reading, \(m\) is the error coefficient, \(p\) is the known (``correct'') pressure and \(k\) is the error constant
% \end{quote}

% Code Snippet:
% \begin{lstlisting}
% .model AKM02 D(Is=1.5n Rs=.5 Cjo=80p M=0.3 Vj=1 nbv=3 bv=6.2 Ibv=1m Vpk=6.2 mfg=OnSemi type=zener)
% \end{lstlisting}

% Bibliography:
% \begin{thebibliography}{99}
%   \bibitem{itemname}
%   Author,
%   Date.
%   \emph{Title}.
%   Edition.
%   Press.
%   \url{http://web.iitd.ac.in/~shouri/eel201/tuts/diode_switch.pdf}
% \end{thebibliography}

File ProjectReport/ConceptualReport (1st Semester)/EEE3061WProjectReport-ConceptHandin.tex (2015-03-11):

\input{woodamble}                                                       % Custom preamble
%----------------------------------------------------------------------------------------
% NAME AND CLASS SECTION
%----------------------------------------------------------------------------------------

\newcommand{\hmwkTitle}{Conceptual Design Report} % Assignment title
\newcommand{\hmwkDueDate}{Wednesday,\ September\ 03,\ 2014}                    % Due date
\newcommand{\hmwkClass}{EEE3061W - Mechatronics Design}                    % Course/class
\newcommand{\hmwkClassTime}{10:30am}                                 % Class/lecture time
\newcommand{\hmwkClassInstructor}{Jones}                               % Teacher/lecturer
\newcommand{\hmwkAuthorName}{Team 13}    % Your name
\newcommand{\hmwkDepartment}{Department of Electrical Engineering}           % Department

%----------------------------------------------------------------------------------------
% TITLE PAGE
%----------------------------------------------------------------------------------------

\title{
\begin{figure}[H]
  \begin{center}
    
  \end{center}
\end{figure}
\textmd{\Huge UNIVERSITY OF CAPETOWN \\ \LARGE \hmwkDepartment} \\
\vspace{2in}
\textmd{\textbf{\LARGE \hmwkClass \\ \Huge Biathlon Robot \\ \hmwkTitle \\ \vspace{1.5in} \Large Team 13 \\  WDXSEA003 \textbar\space PRSSAM004 \textbar\space RJDYAR001 \textbar\space STRIBR001}}\\
%\normalsize\vspace{0.1in}\small{Due\ on\ \hmwkDueDate}\\
%\vspace{0.1in}\large{\textit{\hmwkClassInstructor\ \hmwkClassTime}}
}

\date{}

%========================================================================================
%========================================================================================

\begin{document}

\maketitle
\clearpage

%----------------------------------------------------------------------------------------
% ABTRACT
%----------------------------------------------------------------------------------------
\setcounter{tocdepth}{2}                                                      % ToC Depth

% \begin{abstract}
% This preliminary report covers the conceptual design stage of the EEE3061W Mechatronics Design 2015 project involving the design and manufacture of a bi-athletic robot.  This robot is to partake in a sprint as well as throw a weighted ping-pong ball.

% \end{abstract}
% \newpage

%----------------------------------------------------------------------------------------
% TABLE OF CONTENTS
%----------------------------------------------------------------------------------------

% \clearpage

% \tableofcontents

% \clearpage

% \listoffigures
% \listoftables

% \clearpage

% %----------------------------------------------------------------------------------------
% % NOMENCLATURE
% %----------------------------------------------------------------------------------------

% \begin{homeworkProblem}[{Nomenclature}]
% \textbf{Constants}

% \(V_{LINE}\) - Nominal Line Voltage\\
% \(A_v\) - Operational Amplifier Gain\\
% \(db_{SPL}\) - Sound Pressure Level\\
% \(\theta_S\) - Phase Shift

% \end{homeworkProblem}

%----------------------------------------------------------------------------------------
% INTRODUCTION
%----------------------------------------------------------------------------------------
\begin{homeworkProblem}[{Introduction}]
This preliminary report and reports hereafter together cover the complete design process for EEE3061W Mechatronics Design Project for 2015.  The project involves the design, manufacture and testing of a legged, autonomous, bi-athletic robot that will be able to partake in a 5m sprint and then throw a weighted ping-pong ball.  The robot is to adhere to a set of specifications as provided by the course management. \\

This report covers purely the initial stage of the design process, that being conceptual designs which are candidates for the final design.  The concepts have been split into logical aspects of the robot itself.

% \begin{homeworkSection}{Project Specifications}
% The project specifications are as follows:

% \begin{itemize}
%   \item Robot will compete in a timed event
%   \item Each robot must start after detecting the green light
%   \item The robot must run in a straight line till it reaches the end - and stay within a 30 cm lane
%   \item The track will contain randomly placed pieces of transparency paper
%   \item It does not need to sense the end of the race
%   \item The robot must only use the two motors provided
%   \item The robot must fit in a volume of 100$\times$150$\times$75 mm
%   \item The robot must be self powered (battery)
%   \item The robot must be autonomous and use the STM32F0xx
%   \item The robot must make provision for a launcher (2nd semester) plus a 50g ping-pong ball
%   \item Definition of legs:
%   \begin{itemize}
%     \item All legs must operate in a cyclic fashion
%     \item No wheels or rotary wheel-like appendages will be permitted for locomotion
%     \item If the drive motor continuously rotates in one direction, leg motion must oscillate back and forth through some form of a cam and/or mechanical linkage
%     \item The entire weight of the robot must be completely supported by the robot's legs
%     \item All legs must separate (lift/hop/move) off the ground at some point during each walk/step cycle (i.e. they cannot slide/roll across the ground)
%   \end{itemize}
%   \item Provided:
%   \begin{itemize}
%     \item 1 A4 sheet of 3mm perspex
%     \item 1 A4 sheet of 3mm hardboard
%   \end{itemize}
%   \item Other allowed items are:
%   \begin{itemize}
%     \item Steel pins
%     \item Rivets
%     \item Glue
%     \item Screws
%     \item String
%     \item Nuts and bolts
%   \end{itemize}
%   \item Max ``out of pocket'' for other components is R100.00
% \end{itemize}

% \end{homeworkSection}
\end{homeworkProblem}

%----------------------------------------------------------------------------------------
% DESIGN CONCEPTS
%----------------------------------------------------------------------------------------
\begin{homeworkProblem}[{Design Concepts}]
\begin{homeworkSection}{Design Concept 1}

\begin{figure}[H]
  \begin{center}
    
    \caption{3D Render of Design Concept 1}
    \label{3dConcept1}
  \end{center}
\end{figure}

Our first design concept is one which incorporates the Klann Linkage system in the leg design. This allows direct conversion of rotary motion from the motors to linear motion in the legs. The body design, which is somewhat complex, is octagonal in shape, with the angled panels fastened using internal brackets bolted onto the inside. This design is aesthetically appealing however, may make it difficult to access the internal components once the design is completed.  Also, the body restricts the height of the gearing system within. The leg system is a standard Klann Linkage with 8 legs. The legs are connected in pairs, situated on each side of the body, which are run by the same gear (i.e. each motor controls one side each of the leg system).  The main advantage of the extra 4 legs is to provide improved stability. Definitive of the Klann Linkage system, each stride lasts for 180 degrees of each revolution, and so having two legs per revolution, the leg group is able to provide at least one leg for the full revolution. This means there will be 4 legs on the ground at all times during the robot's motion. Although not shown in the rendering, the gearing system would have the final output on the outside of the main body, with the gears placed between the rotating disks. This prevents physical interference at any point during the leg cycles.\\

The rendering is not necessarily to scale or proportion.  Due to restrictions in volume and dimensions, the legs would be shorter and body closer to the ground.
\end{homeworkSection}

\begin{homeworkSection}{Design Concept 2}

\begin{figure}[H]
  \begin{center}
    
    \caption{3D Render of Design Concept 2}
    \label{3dConcept2}
  \end{center}
\end{figure}

The second design concept is somewhat similar to the previous one, but with one important difference: the left and right leg pairings are driven by a single, central driving gear. The main body of the robot is also similar to the previous design, but with an open rear to make it easier to access internal components. The front of the main body acts primarily as a visor to help protect the components to some extent during the motion. This is also an attempt to minimize weight, but compromises the aesthetic appeal as all the components will be visible. The same 8-leg Klann Linkage system is employed here as well. The gearing system and motor placement will be the same as the previous concept, as the ratios and general internal configuration will be the same.

\end{homeworkSection}

\begin{homeworkSection}{Design Concept 3}

\begin{figure}[H]
  \begin{center}
    
    \caption{3D Render of Design Concept 3}
    \label{3dConcept3}
  \end{center}
\end{figure}

The third and final design again employs the Klann Linkage system. The primary difference is that the legs are now placed closer towards the front and back of the main body rather than on the sides. The general body shape is box-like as this will be most efficient to accommodate this particular leg system. The motor and gear placement would also be different: they would be placed on the front and back, with the circuitry and control system placed more centrally. The 8-piece Klann Linkage legs would be most stable in this orientation and allow greater body width. This implementation, however, will result in an overall loss in body length. 

\end{homeworkSection}
\end{homeworkProblem}

\clearpage

\begin{homeworkProblem}[{Final Concept}]
The following table (Table \ref{comparison1}1) compares the pros and cons of each design concept in order to analyze the merits and shortfalls of each concept.

\begin{table}[h]
\centering
\begin{tabular}{cccccc}
\hline
\multicolumn{2}{c}{\cellcolor[HTML]{E3E3E3}{\color[HTML]{000000} \textbf{Design Concept 1}}} & \multicolumn{2}{c}{\cellcolor[HTML]{E3E3E3}{\color[HTML]{000000} \textbf{Design Concept 2}}} & \multicolumn{2}{c}{\cellcolor[HTML]{E3E3E3}{\color[HTML]{000000} \textbf{Design Concept 3}}} \\ \hline
\multicolumn{1}{c|}{\textbf{Pros}} & \multicolumn{1}{c|}{\textbf{Cons}} & \multicolumn{1}{c|}{\textbf{Pros}} & \multicolumn{1}{c|}{\textbf{Cons}} & \multicolumn{1}{c|}{\textbf{Pros}} & \textbf{Cons} \\ \hline
\multicolumn{1}{c|}{\begin{tabular}[c]{@{}c@{}}Great\\ stability\end{tabular}} & \multicolumn{1}{c|}{\begin{tabular}[c]{@{}c@{}}May be\\ heavy\end{tabular}} & \multicolumn{1}{c|}{\begin{tabular}[c]{@{}c@{}}High\\ stability\end{tabular}} & \multicolumn{1}{c|}{\begin{tabular}[c]{@{}c@{}}More\\ complex\\ mechanism\end{tabular}} & \multicolumn{1}{c|}{\begin{tabular}[c]{@{}c@{}}Improved\\ longitudinal\\ stability\end{tabular}} & \begin{tabular}[c]{@{}c@{}}Limited\\ longitudinal\\ length\end{tabular} \\ \hline
\multicolumn{1}{c|}{\begin{tabular}[c]{@{}c@{}}Reasonable\\ speed\end{tabular}} & \multicolumn{1}{c|}{\begin{tabular}[c]{@{}c@{}}Difficult\\ body\\ assembly\end{tabular}} & \multicolumn{1}{c|}{\begin{tabular}[c]{@{}c@{}}Good\\ maneuverability\end{tabular}} & \multicolumn{1}{c|}{\begin{tabular}[c]{@{}c@{}}Low\\ protection\\ of parts\end{tabular}} & \multicolumn{1}{c|}{\begin{tabular}[c]{@{}c@{}}Higher\\ speed\end{tabular}} & \begin{tabular}[c]{@{}c@{}}Difficult\\ part\\ placement\end{tabular} \\ \hline
\multicolumn{1}{c|}{\begin{tabular}[c]{@{}c@{}}Good\\ maneuverability\end{tabular}} & \multicolumn{1}{c|}{\begin{tabular}[c]{@{}c@{}}Difficult\\ access\end{tabular}} & \multicolumn{1}{c|}{\begin{tabular}[c]{@{}c@{}}Easier\\ assembly\end{tabular}} & \multicolumn{1}{c|}{\begin{tabular}[c]{@{}c@{}}Limit\\ lateral\\ space/width\end{tabular}} & \multicolumn{1}{c|}{\begin{tabular}[c]{@{}c@{}}More\\ lateral\\ width\end{tabular}} & \begin{tabular}[c]{@{}c@{}}Difficult\\ to assemble\end{tabular} \\ \hline
\multicolumn{1}{c|}{\begin{tabular}[c]{@{}c@{}}Good\\ part\\ orientation\end{tabular}} & \multicolumn{1}{c|}{\begin{tabular}[c]{@{}c@{}}Limited\\ lateral\\ space/width\end{tabular}} & \multicolumn{1}{c|}{\begin{tabular}[c]{@{}c@{}}Ease\\ of access\end{tabular}} & \multicolumn{1}{c|}{} & \multicolumn{1}{c|}{} & \begin{tabular}[c]{@{}c@{}}More\\ machining\\ required\end{tabular} \\ \hline
\multicolumn{1}{c|}{} & \multicolumn{1}{c|}{\begin{tabular}[c]{@{}c@{}}More\\ gears\\ required\end{tabular}} & \multicolumn{1}{c|}{\begin{tabular}[c]{@{}c@{}}Less\\ gears\\ needed\end{tabular}} & \multicolumn{1}{c|}{} & \multicolumn{1}{c|}{} &  \\ \hline
\end{tabular}

\label{comparison1}
\caption{Table of pros and cons for each of the three design concepts}
\end{table}

Given the pros and cons of each, a combination of the leg design from concept 1 and the body design from concept 2 was decided upon. This provides a good speed design, a simple but functional body design, as well as good weight distribution with the gears placed at the back, while the battery pack placed is at the front.\\

Figure 3.1 below shows a conceptual feature plan of the above chosen design:

\begin{figure}[H]
  \begin{center}
    
    \caption{Conceptual feature plan and component placement diagram}
    \label{moduleplanview1}
  \end{center}
\end{figure}

\begin{figure}[H]
  \begin{center}
    
    \caption{Diagram of the Klann Linkage System}
    \label{klannLinkage1}
  \end{center}
\end{figure}

\begin{homeworkSection}{Other Design Considerations}
The Jansen linkage was another concept that we considered for the legs. Its primary advantage over the Klann linkage is that it is notably faster. It is also more stable when dealing with obstacles. Despite this, however, the linkage system as well as its complex implementation would be considerably more difficult. The increased number of linkages per leg would make assembly as well as dimensioning and optimizing very difficult. This is the primary reason why we decided not to consider it for our final design.
\end{homeworkSection}

\begin{homeworkSection}{Potential Improvements}
One possible design improvement would be to implement the use of oval gears instead of circular for the final output gear. By doing this with the correct orientation, the legs would have a longer contact time with the ground as the downward motion would be slower. This would serve to increase the torque of each leg. As well as this, the upward leg motion would be faster, resulting in a shorter stride time and an overall increase in speed because a smaller gear ratio would then be used.\\

As mentioned above, the legs should be shortened and widened, offering more height to the body, lower center of gravity for stability and extra strength in the legs.
\end{homeworkSection}
\end{homeworkProblem}

%----------------------------------------------------------------------------------------
% PRELIMINARY CALCULATIONS
%----------------------------------------------------------------------------------------
\begin{homeworkProblem}[{Preliminary Calculations}]
\begin{homeworkSection}{Gear Ratio}

The gear ratio is entirely dependent of the minimum torque that would be required per leg in order to move the robot forward. As per the specifications, the output rpm of the motors is too high to directly drive the legs whilst providing enough torque to overcome the inertia of the body. An initial calculation for the minimum torque would be enough to determine the best gear ratio.\\

\begin{equation}
  \text{Torque} = \text{force}\times\text{distance}
\end{equation}

The weight of the overall design, as well as its perpendicular distance from the legs in contact with the ground would easily determine the minimum torque needed in order to drive the robot. \\

Mass of Robot = 510g \\
Distance from Leg = 7.5 cm

\begin{equation*}
\begin{split}
  \therefore \text{Torque} &= \frac{510\left(7.5\right)}{2}\\
                           &\approx 1913 \text{g}\cdot\text{cm}
\end{split}
\end{equation*}

Given that the ratio of the input and output torque would be the same as the gear ratio, the final gear ratio would therefore be:

\begin{equation*}
\begin{split}
  \text{Ratio} &= \frac{1913}{220} \\
               &\approx 9
\end{split}
\end{equation*}

The gear arrangement can be seen in Fig. 3.1. 

\end{homeworkSection}

\begin{homeworkSection}{Weight Budget}

\begin{table}[H]
\centering
\begin{tabular}{|c|c|}
\hline
\rowcolor[HTML]{D9D9D9} 
\textbf{Item/Material}                                                        & \textbf{Mass (g)} \\ \hline
Gears/sprockets                                                               & 50                \\ \hline
Nuts and Bolts                                                                & 30                \\ \hline
Legs (Perspex and Wood)                                                       & 100               \\ \hline
Pins                                                                          & 20                \\ \hline
Rubber Feet                                                                   & 10                \\ \hline
\begin{tabular}[c]{@{}c@{}}Body/Casing \\ (Perspex and Wood)\end{tabular}     & 135               \\ \hline
\begin{tabular}[c]{@{}c@{}}PCB (including components\\ and wire)\end{tabular} & 175               \\ \hline
Battery                                                                       & 20                \\ \hline
\rowcolor[HTML]{D9FFA4} 
\multicolumn{1}{|r|}{\cellcolor[HTML]{D9FFA4}\textbf{TOTAL}}                  & 510               \\ \hline
\end{tabular}

\label{weightBudget1}
\caption{Table showing a budget of the weight of the robot by individual components/materials}
\end{table}

\end{homeworkSection}
\end{homeworkProblem}

\end{document}
%----------------------------------------------------------------------------------------
% INSTRUCTIONS AND TEMPLATE COMPONENTS
%----------------------------------------------------------------------------------------

% Document is structured in --> [document]
%                                 [homeworkProblem]
%                                   [homeworkSection]
%                                     [COMPONENTS]

% Set space - \vspace{length}
% Horizontal line - \hrule
% Pagebreak - \clearpage or \newpage - they seem to do the same thing

% Normal equation:
% \begin{equation}
%   p = \frac{p_g - k}{m}
% \end{equation}

% Aligned equation:
% \begin{equation}
%   \begin{split}
%     \rho_5  & = -\frac{\left(1575-1900\right)}{g\left(105\e{-3}-70\e{-3}\right)}\\
%             & = 946.56 \text{ kg/m\(^{-3}\)}\\
%     \rho_6  & = -\frac{\left(1900-2150\right)}{g\left(70\e{-3}-42\e{-3}\right)}\\
%             & = 910.15 \text{ kg/m\(^{-3}\)}\\
%   \end{split}
% \end{equation}

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

% Picture:
% \begin{figure}[H]
%   \begin{center}
%     \includegraphics[width=0.4\columnwidth]{MEC2022SLab1Exp1}
%     \caption{Apparatus}
%     \label{liquidDiagram}
%   \end{center}
% \end{figure}

% Graph:
% \begin{figure}[H]
%   \centering
%   \begin{tikzpicture}
%     \begin{axis}[
%       xlabel=Known Weight (Psi),
%       ylabel=Reading (Psi),
%       grid=major]
%     \addplot[color=red, smooth] coordinates {
%       (22,9.43)
%       (27,13.78)
%     };
%     \addlegendentry{Gauge}
    
%     \addplot[color=blue, dashed, smooth] coordinates {
%       (22,22)
%       (27,27)
%     };
%     \addlegendentry{Known weight}
    
%     \end{axis}
%   \end{tikzpicture}
%   \caption{Dead weight tester and gauge measurements}
%   \label{gaugePlot}
% \end{figure}

% Indented Text: (bit of a hacky way to do it)
% \begin{quote}
% where \(p_g\) is the gauge reading, \(m\) is the error coefficient, \(p\) is the known (``correct'') pressure and \(k\) is the error constant
% \end{quote}

% Code Snippet:
% \begin{lstlisting}
% .model AKM02 D(Is=1.5n Rs=.5 Cjo=80p M=0.3 Vj=1 nbv=3 bv=6.2 Ibv=1m Vpk=6.2 mfg=OnSemi type=zener)
% \end{lstlisting}

% Bibliography:
% \begin{thebibliography}{99}
%   \bibitem{itemname}
%   Author,
%   Date.
%   \emph{Title}.
%   Edition.
%   Press.
%   \url{http://web.iitd.ac.in/~shouri/eel201/tuts/diode_switch.pdf}
% \end{thebibliography}

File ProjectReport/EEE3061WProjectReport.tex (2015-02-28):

\input{woodamble}                                                       % Custom preamble
%----------------------------------------------------------------------------------------
% NAME AND CLASS SECTION
%----------------------------------------------------------------------------------------

\newcommand{\hmwkTitle}{Project Report} % Assignment title
\newcommand{\hmwkDueDate}{Wednesday,\ September\ 03,\ 2014}                    % Due date
\newcommand{\hmwkClass}{EEE3061W - Mechatronics Design}                    % Course/class
\newcommand{\hmwkClassTime}{10:30am}                                 % Class/lecture time
\newcommand{\hmwkClassInstructor}{Jones}                               % Teacher/lecturer
\newcommand{\hmwkAuthorName}{WDXSEA003 \textbar \space PRSSAM004 \textbar \space RJDYAR001 \textbar \space STRIBR001}    % Your name
\newcommand{\hmwkDepartment}{Department of Electrical Engineering}           % Department

%----------------------------------------------------------------------------------------
% TITLE PAGE
%----------------------------------------------------------------------------------------

\title{
\begin{figure}[H]
  \begin{center}
    
  \end{center}
\end{figure}
\textmd{\Huge UNIVERSITY OF CAPETOWN \\ \LARGE \hmwkDepartment} \\
\vspace{2in}
\textmd{\textbf{\LARGE \hmwkClass\\ \Huge Biathlon Robot \\ \hmwkTitle \\ \vspace{1.5in} \Large Team 13 \\  \hmwkAuthorName}}\\
%\normalsize\vspace{0.1in}\small{Due\ on\ \hmwkDueDate}\\
%\vspace{0.1in}\large{\textit{\hmwkClassInstructor\ \hmwkClassTime}}
}

\date{}

%========================================================================================
%========================================================================================

\begin{document}

\maketitle
\clearpage

%----------------------------------------------------------------------------------------
% ABTRACT
%----------------------------------------------------------------------------------------
\setcounter{tocdepth}{2}                                                      % ToC Depth

\begin{abstract}
This report covers the design procedure and results for an active noise cancelling headset preamplifier which performed to the specified requirements when simulated and demonstrated reasonable noise cancelling characteristics.
\end{abstract}
% \newpage

%----------------------------------------------------------------------------------------
% TABLE OF CONTENTS
%----------------------------------------------------------------------------------------

\clearpage

\tableofcontents

\clearpage

\listoffigures
\listoftables

\clearpage

%----------------------------------------------------------------------------------------
% NOMENCLATURE
%----------------------------------------------------------------------------------------

\begin{homeworkProblem}[{Nomenclature}]
\textbf{Constants}

\(V_{LINE}\) - Nominal Line Voltage\\
\(A_v\) - Operational Amplifier Gain\\
\(db_{SPL}\) - Sound Pressure Level\\
\(\theta_S\) - Phase Shift

\end{homeworkProblem}
%----------------------------------------------------------------------------------------
% INTRODUCTION
%----------------------------------------------------------------------------------------
\begin{homeworkProblem}[{Introduction}]
% Graph:
\begin{figure}[H]
  \centering
  \begin{tikzpicture}
    \begin{axis}[
      xlabel=Known Weight (Psi),
      ylabel=Reading (Psi),
      grid=major]
    \addplot[color=red, smooth] coordinates {
      (22,9.43)
      (23, 2)
      (27,13.78)
      (29,17)
    };
    \addlegendentry{Gauge}
    
    \addplot[color=blue, dashed, smooth] coordinates {
      (22,22)
      (27,27)
    };
    \addlegendentry{Known weight}
    
    \end{axis}
  \end{tikzpicture}
  \caption{Dead weight tester and gauge measurements}
  \label{gaugePlot}
\end{figure}

\end{homeworkProblem}

\end{document}

%----------------------------------------------------------------------------------------
% INSTRUCTIONS AND TEMPLATE COMPONENTS
%----------------------------------------------------------------------------------------

% Document is structured in --> [document]
%                                 [homeworkProblem]
%                                   [homeworkSection]
%                                     [COMPONENTS]

% Set space - \vspace{length}
% Horizontal line - \hrule
% Pagebreak - \clearpage or \newpage - they seem to do the same thing

% Normal equation:
% \begin{equation}
%   p = \frac{p_g - k}{m}
% \end{equation}

% Aligned equation:
% \begin{equation}
%   \begin{split}
%     \rho_5  & = -\frac{\left(1575-1900\right)}{g\left(105\e{-3}-70\e{-3}\right)}\\
%             & = 946.56 \text{ kg/m\(^{-3}\)}\\
%     \rho_6  & = -\frac{\left(1900-2150\right)}{g\left(70\e{-3}-42\e{-3}\right)}\\
%             & = 910.15 \text{ kg/m\(^{-3}\)}\\
%   \end{split}
% \end{equation}

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

% Picture:
% \begin{figure}[H]
%   \begin{center}
%     \includegraphics[width=0.4\columnwidth]{MEC2022SLab1Exp1}
%     \caption{Apparatus}
%     \label{liquidDiagram}
%   \end{center}
% \end{figure}

% Graph:
% \begin{figure}[H]
%   \centering
%   \begin{tikzpicture}
%     \begin{axis}[
%       xlabel=Known Weight (Psi),
%       ylabel=Reading (Psi),
%       grid=major]
%     \addplot[color=red, smooth] coordinates {
%       (22,9.43)
%       (27,13.78)
%     };
%     \addlegendentry{Gauge}
    
%     \addplot[color=blue, dashed, smooth] coordinates {
%       (22,22)
%       (27,27)
%     };
%     \addlegendentry{Known weight}
    
%     \end{axis}
%   \end{tikzpicture}
%   \caption{Dead weight tester and gauge measurements}
%   \label{gaugePlot}
% \end{figure}

% Indented Text: (bit of a hacky way to do it)
% \begin{quote}
% where \(p_g\) is the gauge reading, \(m\) is the error coefficient, \(p\) is the known (``correct'') pressure and \(k\) is the error constant
% \end{quote}

% Code Snippet:
% \begin{lstlisting}
% .model AKM02 D(Is=1.5n Rs=.5 Cjo=80p M=0.3 Vj=1 nbv=3 bv=6.2 Ibv=1m Vpk=6.2 mfg=OnSemi type=zener)
% \end{lstlisting}

% Bibliography:
% \begin{thebibliography}{99}
%   \bibitem{itemname}
%   Author,
%   Date.
%   \emph{Title}.
%   Edition.
%   Press.
%   \url{http://web.iitd.ac.in/~shouri/eel201/tuts/diode_switch.pdf}
% \end{thebibliography}

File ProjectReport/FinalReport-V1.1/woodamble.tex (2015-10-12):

%TODO! - Proper citations

%----------------------------------------------------------------------------------------
% PACKAGES AND OTHER DOCUMENT CONFIGURATIONS
%----------------------------------------------------------------------------------------

\documentclass[a4paper]{article}
\usepackage{fontspec}
\usepackage[autostyle]{csquotes}

% == Package includes
\usepackage[backend=biber, style=ieee]{biblatex}              % Biblatex with IEEE Config
  \addbibresource{references.bib}
\usepackage{booktabs}                                                    % Table support|
\usepackage[table]{xcolor}                                               %              |
%\usepackage[a4paper,bindingoffset=-0.1in,left=1in,right=1in,top=1in,bottom=1in,footskip=1in]{geometry}
\usepackage{fancyhdr}                                       % Required for custom headers
\usepackage{lastpage}                % Required to determine the last page for the footer
\usepackage{extramarks}                                % Required for headers and footers
\usepackage{graphicx}                                         % Required to insert images
\usepackage{lipsum}       % Used for inserting dummy 'Lorem ipsum' text into the template
\usepackage[english]{babel}                                % English language/hyphenation
\usepackage{mathtools}                                                    % Math packages
\usepackage{mathabx}
%\usepackage{amsmath,amsfonts,amsthm}                        % Math packages (deprecated)
\usepackage{float}                                              % Images and other floats
\usepackage[section]{placeins}                                      % Placement of floats
\usepackage{color}                                                       % Colour support
\usepackage{tikz}
\usepackage{pgfplots}
  \pgfplotsset{compat=1.11}
\usepackage{chngcntr}                                           % Figure counter settings
\usepackage[hidelinks]{hyperref}                                             % Hyperlinks
\usepackage{epstopdf}                                               % EPS graphic support
\usepackage{pygmentex}                                       % Code snippet color support
\usepackage{listings}                                              % Code snippet support
\usepackage{minted}                                                       % Code snippets

% == Colour Definitions
\definecolor{dkgreen}{rgb}{0,0.6,0}
\definecolor{gray}{rgb}{0.93,0.93,0.93}
\definecolor{mauve}{rgb}{0.58,0,0.82}

% == Code Snippet Config
\DeclareBoolOption[true]{cache}
\setmonofont{Consolas}
\usemintedstyle{friendly}
\setminted{ bgcolor=gray,
            fontsize=\small}
\lstset{frame=tb,
  aboveskip=3mm,
  belowskip=3mm,
  showstringspaces=false,
  columns=flexible,
  basicstyle={\small\ttfamily},
  numbers=none,
  breaklines=true,
  breakatwhitespace=true
  tabsize=3
}

\providecommand{\e}[1]{\ensuremath{\times 10^{#1}}}                % Scientific Notation!
\providecommand{\eoc}{\ensuremath{_{\slash \slash \slash}}}           % End of Calculation Symbol!
%\flushbottom

%----------------------------------------------------------------------------------------
% DOCUMENT STRUCTURE COMMANDS
%----------------------------------------------------------------------------------------

% == Numbering

\makeatletter

\newcommand\frontmatter{%
    \cleardoublepage
  %\@mainmatterfalse
  \pagenumbering{roman}}

\newcommand\mainmatter{%
    \cleardoublepage
 % \@mainmattertrue
  \pagenumbering{arabic}}

\newcommand\backmatter{%
  \if@openright
    \cleardoublepage
  \else
    \clearpage
  \fi
 % \@mainmatterfalse
   }

\makeatother

% == Margins
\topmargin=-0.45in                                   % Deprecated due to geometry package
\evensidemargin=0in
\oddsidemargin=0in
\textwidth=6.5in
\textheight=10in
\headsep=0.25in
\setlength\parindent{0pt}                       % Removes all indentation from paragraphs
\linespread{1.1}                                                           % Line spacing

% == Header and Footer
\pagestyle{fancy}
\lhead{\footnotesize\reportAuthorName}                                    % Top left header
\chead{}                                                              % Top center header
\rhead{\firstxmark\reportClass\ | \reportTitle}                      % Top right header\first
\lfoot{\lastxmark}                                                   % Bottom left footer
\cfoot{}                                                           % Bottom center footer
\rfoot{Page\ \thepage}                                              % Bottom right footer
\renewcommand\headrulewidth{0.4pt}                              % Size of the header rule
\renewcommand\footrulewidth{0.3pt}                              % Size of the footer rule

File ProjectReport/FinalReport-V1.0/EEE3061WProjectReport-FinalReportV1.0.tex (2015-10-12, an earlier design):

\input{woodamble}                                                       % Custom preamble
%----------------------------------------------------------------------------------------
% NAME AND CLASS SECTION
%----------------------------------------------------------------------------------------

\newcommand{\reportTitle}{Final Report} % Assignment title
\newcommand{\reportDueDate}{Wednesday,\ September\ 03,\ 2014}                    % Due date
\newcommand{\reportClass}{EEE3061W - Mechatronics Design}                               % Course/class
\newcommand{\reportClassTime}{10:30am}                                 % Class/lecture time
\newcommand{\reportClassInstructor}{Jones}                               % Teacher/lecturer
\newcommand{\reportAuthorName}{Team 13}                           % Your name
\newcommand{\reportDepartment}{Department of Electrical Engineering}           % Department

%----------------------------------------------------------------------------------------
% TITLE PAGE
%----------------------------------------------------------------------------------------

\title{
\begin{figure}[H]
  \begin{center}
    
  \end{center}
\end{figure}
\textmd{\Huge UNIVERSITY OF CAPE TOWN \\ \LARGE \reportDepartment} \\
\vspace{2in}
\textmd{\textbf{\LARGE \reportClass \\ \Huge Biathlon Robot \\ \reportTitle \\ \vspace{1.5in} \Large Team 13 \\  WDXSEA003 \textbar\space PRSSAM004 \textbar\space RJDYAR001 \textbar\space STRIBR001}}\\
}

\date{}

%========================================================================================
%========================================================================================

\begin{document}
  \maketitle
  \thispagestyle{empty}

\frontmatter
%----------------------------------------------------------------------------------------
% ABTRACT
%----------------------------------------------------------------------------------------
\setcounter{tocdepth}{2}                                                      % ToC Depth
\setcounter{secnumdepth}{2}                                     % Section Numbering Depth

\begin{abstract}
  \thispagestyle{empty}
  This report covers the conceptualization, design and building stages of an autonomous bi-athletic robot for the EEE3061W Mechatronics Design Project 2015.  This robot was to partake in a sprint as well as launch a ping-pong ball after tracking a line and being aware of the end of the course. % TODO Add more here...

\end{abstract}

%----------------------------------------------------------------------------------------
% TABLE OF CONTENTS
%----------------------------------------------------------------------------------------

\cleardoublepage
\addcontentsline{toc}{section}{Table of Contents}
\tableofcontents

\clearpage
\section*{List of Illustrations}
\addcontentsline{toc}{section}{List of Illustrations}
\label{sec:List of Illustrations}
\addcontentsline{toc}{subsection}{List of Figures}
\listoffigures
\addcontentsline{toc}{subsection}{List of Tables}
\listoftables

\clearpage

%----------------------------------------------------------------------------------------
% GLOSSARY
%----------------------------------------------------------------------------------------
\section*{Glossary}
\addcontentsline{toc}{section}{Glossary}
\label{sec:Glossary}
\vspace{2cm}
\begin{tabular}{@{}p{6cm}@{\hspace{0.5cm}}p{9cm}@{\vspace{0.5cm}}}
  \bfseries MEMS & MicroElectroMechanicalSystem \\
\end{tabular}

% ----- Report Layout Plan -----
% - Abstract
% - Introduction
%   - Sprinter Introduction
%   - Launcher Introduction
%
% Sprinter Stuff
% - Sprinter Design Concepts
%   - Design Concept 1
%   - Design Concept 2
%   - Design Concept 3
% - Sprinter Final Concept
% - Sprinter Preliminary Calculations
% - Sprinter Mechanical Design
% - Sprinter Electronic Design
%   - Core electronics (Controller board)
%   - Peripheral electronics (Power board, LEDs, Sensors etc)
% - Sprinter Control and Software
%   - Control Principles
%   - Software structure choice
%   - Other details like gyro etc
% - Sprinter Build, Testing and Calibration
% - Sprinter Results and Conclusions
%
% Launcher Stuff
% - Launcher Design Concepts
%   - Design Concept 1
%   - Design Concept 2
%   - Design Concept 3
% - Launcher Final Concept
% - Launcher Preliminary Calculations
% - Launcher Mechanical Design
% - Launcher Electronic Design
%   - Core electronics (Controller board)
%   - Peripheral electronics (Power board, LEDs, Sensors etc)
% - Launcher Control and Software
%   - Control principles
%   - Software structure choice and a note on RTOS
%   - Other details
% - Launcher Build, Testing and Calibration
% - Launcher Results and Conclusions
%
% - Final Conclusion
% - APPENDICES

%----------------------------------------------------------------------------------------
% NOMENCLATURE
%----------------------------------------------------------------------------------------
\section*{Nomenclature}
\addcontentsline{toc}{section}{Nomenclature}
\label{sec:Nomenclature}

\textbf{Constants}

\(V_{LINE}\) - Nominal Line Voltage\\
\(A_v\) - Operational Amplifier Gain\\
\(db_{SPL}\) - Sound Pressure Level\\
\(\theta_S\) - Phase Shift

%----------------------------------------------------------------------------------------
% INTRODUCTION
%----------------------------------------------------------------------------------------
\mainmatter
\section{Introduction}
\label{sec:Introduction}
  This report covers the complete design process for EEE3061W Mechatronics Design Project for 2015.  The project involves the design, manufacture and testing of a legged, autonomous, bi-athletic robot that will be able to partake in a 5m sprint and then throw a weighted ping-pong ball.  The robot is to adhere to a set of specifications as provided by the course management. \\

  The entire project is split into two sections, each covering the semester's task.  The first section involved the sprinting aspect of the robot, and the second involved line following and launching.  The relevant sections are named accordingly.

  \subsection{Sprinter Introduction}
  \label{sub:Sprinter Introduction}
    In summary, the sprinting robot was to make use of a digital 3-axis gyroscope in an attempt to sprint 5m as fast as possible within a f ixed-width lane (maintain fixed heading).  The robot was also specified to start the sprint when green light from a set of three lights was detected, signaling the beginning of the race. \\

    The locomotion design was constrained to the use of legs, making use of a mechanical linkage-type system to convert rotational motion from the provided motors into linear motion to move forward.  Other restrictions included the dimensions of the entire robot and out-of-pocket components budget.

  \subsection{Launcher Introduction}
  \label{sub:Launcher Introduction}
    The second stage of the project required the robot to first navigate along a line (autonomously) into a box and then throw a weighted ping-pong ball as far as possible. The launching mechanism was limited to the use of a lever system, driven by a DC motor provided.  The rest of the restrictions follow from the Sprinter as well. \\

  The development of both robots followed the same design process whereby 3 conceptual designs were proposed and one final design (or a combination of ideas from more than one) was developed upon further after having drawn up a pros and cons comparison.  The final design was, at this stage, separated into the electronic and mechanical aspects.  As such, they are discussed separately.  Mechanical designs were modelled using 3D CAD (either SolidWorks or AutoDesk Inventor) and electronics were drawn up in Altium Designer.

%----------------------------------------------------------------------------------------
% SPRINTER DESIGN CONCEPTS
%----------------------------------------------------------------------------------------

\clearpage
\part{Sprinter}
\label{part:sprinter}

\section{Sprinter Design Concepts}
\label{sec:Sprinter Design Concepts}
  \subsection{Design Concept 1}
  \label{sub:Design Concept 1}
    \begin{figure}[H]
    \label{fig:3dConcept1}
      \begin{center}
        
        \caption{3D Render of Sprinter Design Concept 1}
      \end{center}
    \end{figure}

    The first sprinter design concept is one which incorporates the Klann Linkage system in the leg design. This allows direct conversion of rotary motion from the motors to linear motion in the legs. The body design, which is somewhat complex, is octagonal in shape, with the angled panels fastened using internal brackets bolted onto the inside. This design is aesthetically appealing however, may make it difficult to access the internal components once the design is completed.  Also, the body restricts the height of the gearing system within. The leg system is a standard Klann Linkage with 8 legs. The legs are connected in pairs, situated on each side of the body, which are run by the same gear (i.e. each motor controls one side each of the leg system).  The main advantage of the extra 4 legs is to provide improved stability. Definitive of the Klann Linkage system, each stride lasts for 180 degrees of each revolution, and so having two legs per revolution, the leg group is able to provide at least one leg for the full revolution. This means there will be 4 legs on the ground at all times during the robot's motion. Although not shown in the rendering, the gearing system would have the final output on the outside of the main body, with the gears placed between the rotating disks. This prevents physical interference at any point during the leg cycles.\\

    The rendering is not necessarily to scale or proportion.  Due to restrictions in volume and dimensions, the legs would be shorter and body closer to the ground.

  \subsection{Design Concept 2}
  \label{sub:Design Concept 2}
    \begin{figure}[H]
      \begin{center}
        
        \caption{3D Render of Design Concept 2}
        \label{fig:3dConcept2}
      \end{center}
    \end{figure}

    The second design concept is somewhat similar to the previous one, but with one important difference: the left and right leg pairings are driven by a single, central driving gear. The main body of the robot is also similar to the previous design, but with an open rear to make it easier to access internal components. The front of the main body acts primarily as a visor to help protect the components to some extent during the motion. This is also an attempt to minimize weight, but compromises the aesthetic appeal as all the components will be visible. The same 8-leg Klann Linkage system is employed here as well. The gearing system and motor placement will be the same as the previous concept, as the ratios and general internal configuration will be the same.

  \subsection{Design Concept 3}
  \label{sub:Design Concept 3}
    \begin{figure}[H]
      \begin{center}
        
        \caption{3D Render of Design Concept 3}
        \label{fig:3dConcept3}
      \end{center}
    \end{figure}

    The third and final design again employs the Klann Linkage system. The primary difference is that the legs are now placed closer towards the front and back of the main body rather than on the sides. The general body shape is box-like as this will be most efficient to accommodate this particular leg system. The motor and gear placement would also be different: they would be placed on the front and back, with the circuitry and control system placed more centrally. The 8-piece Klann Linkage legs would be most stable in this orientation and allow greater body width. This implementation, however, will result in an overall loss in body length.

%----------------------------------------------------------------------------------------
% SPRINTER FINAL CONCEPT
%----------------------------------------------------------------------------------------
\section{Sprinter Final Concept}
\label{sec:Sprinter Final Concept}
  The following table (Table \ref{tab:comparison1}) compares the pros and cons of each design concept in order to analyze the merits and shortfalls of each concept.

  \begin{table}[h]
  \centering
  \begin{tabular}{cccccc}
  \hline
  \multicolumn{2}{c}{\cellcolor[HTML]{E3E3E3}{\color[HTML]{000000} \textbf{Design Concept 1}}} & \multicolumn{2}{c}{\cellcolor[HTML]{E3E3E3}{\color[HTML]{000000} \textbf{Design Concept 2}}} & \multicolumn{2}{c}{\cellcolor[HTML]{E3E3E3}{\color[HTML]{000000} \textbf{Design Concept 3}}} \\ \hline
  \multicolumn{1}{c|}{\textbf{Pros}} & \multicolumn{1}{c|}{\textbf{Cons}} & \multicolumn{1}{c|}{\textbf{Pros}} & \multicolumn{1}{c|}{\textbf{Cons}} & \multicolumn{1}{c|}{\textbf{Pros}} & \textbf{Cons} \\ \hline
  \multicolumn{1}{c|}{\begin{tabular}[c]{@{}c@{}}Great\\ stability\end{tabular}} & \multicolumn{1}{c|}{\begin{tabular}[c]{@{}c@{}}May be\\ heavy\end{tabular}} & \multicolumn{1}{c|}{\begin{tabular}[c]{@{}c@{}}High\\ stability\end{tabular}} & \multicolumn{1}{c|}{\begin{tabular}[c]{@{}c@{}}More\\ complex\\ mechanism\end{tabular}} & \multicolumn{1}{c|}{\begin{tabular}[c]{@{}c@{}}Improved\\ longitudinal\\ stability\end{tabular}} & \begin{tabular}[c]{@{}c@{}}Limited\\ longitudinal\\ length\end{tabular} \\ \hline
  \multicolumn{1}{c|}{\begin{tabular}[c]{@{}c@{}}Reasonable\\ speed\end{tabular}} & \multicolumn{1}{c|}{\begin{tabular}[c]{@{}c@{}}Difficult\\ body\\ assembly\end{tabular}} & \multicolumn{1}{c|}{\begin{tabular}[c]{@{}c@{}}Good\\ maneuverability\end{tabular}} & \multicolumn{1}{c|}{\begin{tabular}[c]{@{}c@{}}Low\\ protection\\ of parts\end{tabular}} & \multicolumn{1}{c|}{\begin{tabular}[c]{@{}c@{}}Higher\\ speed\end{tabular}} & \begin{tabular}[c]{@{}c@{}}Difficult\\ part\\ placement\end{tabular} \\ \hline
  \multicolumn{1}{c|}{\begin{tabular}[c]{@{}c@{}}Good\\ maneuverability\end{tabular}} & \multicolumn{1}{c|}{\begin{tabular}[c]{@{}c@{}}Difficult\\ access\end{tabular}} & \multicolumn{1}{c|}{\begin{tabular}[c]{@{}c@{}}Easier\\ assembly\end{tabular}} & \multicolumn{1}{c|}{\begin{tabular}[c]{@{}c@{}}Limit\\ lateral\\ space/width\end{tabular}} & \multicolumn{1}{c|}{\begin{tabular}[c]{@{}c@{}}More\\ lateral\\ width\end{tabular}} & \begin{tabular}[c]{@{}c@{}}Difficult\\ to assemble\end{tabular} \\ \hline
  \multicolumn{1}{c|}{\begin{tabular}[c]{@{}c@{}}Good\\ part\\ orientation\end{tabular}} & \multicolumn{1}{c|}{\begin{tabular}[c]{@{}c@{}}Limited\\ lateral\\ space/width\end{tabular}} & \multicolumn{1}{c|}{\begin{tabular}[c]{@{}c@{}}Ease\\ of access\end{tabular}} & \multicolumn{1}{c|}{} & \multicolumn{1}{c|}{} & \begin{tabular}[c]{@{}c@{}}More\\ machining\\ required\end{tabular} \\ \hline
  \multicolumn{1}{c|}{} & \multicolumn{1}{c|}{\begin{tabular}[c]{@{}c@{}}More\\ gears\\ required\end{tabular}} & \multicolumn{1}{c|}{\begin{tabular}[c]{@{}c@{}}Less\\ gears\\ needed\end{tabular}} & \multicolumn{1}{c|}{} & \multicolumn{1}{c|}{} &  \\ \hline
  \end{tabular}
  \label{tab:comparison1}
  \caption{Table of pros and cons for each of the three design concepts}
  \end{table}

  Given the pros and cons of each, a combination of the leg design from concept 1 and the body design from concept 2 was decided upon. This provides a good speed design, a simple but functional body design, as well as good weight distribution with the gears placed at the back, while the battery pack placed is at the front.\\

  Figure~\ref{fig:moduleplanview1}  below shows a conceptual feature plan of the above chosen design:

  \begin{figure}[H]
    \begin{center}
      
      \caption{Conceptual feature plan and component placement diagram}
      \label{fig:moduleplanview1}
    \end{center}
  \end{figure}

  \begin{figure}[H]
    \begin{center}
      
      \caption{Diagram of the Klann Linkage System}
      \label{fig:klannLinkage1}
    \end{center}
  \end{figure}

  \subsection{Other Design Considerations}
  \label{sub:Other Design Considerations}
    The Jansen linkage was another concept that we considered for the legs. Its primary advantage over the Klann linkage is that it is notably faster. It is also more stable when dealing with obstacles. Despite this, however, the linkage system as well as its complex implementation would be considerably more difficult. The increased number of linkages per leg would make assembly as well as dimensioning and optimizing very difficult. This is the primary reason why we decided not to consider it for our final design.

  \subsection{Potential Improvements}
  \label{sub:Potential Improvements}
    One possible design improvement would be to implement the use of oval gears instead of circular for the final output gear. By doing this with the correct orientation, the legs would have a longer contact time with the ground as the downward motion would be slower. This would serve to increase the torque of each leg. As well as this, the upward leg motion would be faster, resulting in a shorter stride time and an overall increase in speed because a smaller gear ratio would then be used.\\

    As mentioned above, the legs should be shortened and widened, offering more height to the body, lower center of gravity for stability and extra strength in the legs.

%----------------------------------------------------------------------------------------
% SPRINTER PRELIMINARY CALCULATIONS
%----------------------------------------------------------------------------------------
\clearpage
\section{Sprinter Preliminary Calculations}
\label{sec:Sprinter Preliminary Calculations}
  \subsection{Gear Ratio}
  \label{sub:Gear Ratio}
    The gear ratio is entirely dependent of the minimum torque that would be required per leg in order to move the robot forward. As per the specifications, the output rpm of the motors is too high to directly drive the legs whilst providing enough torque to overcome the inertia of the body. An initial calculation for the minimum torque would be enough to determine the best gear ratio.\\

    \begin{equation}
      \text{Torque} = \text{force}\times\text{distance}
    \end{equation}

    The weight of the overall design, as well as its perpendicular distance from the legs in contact with the ground would easily determine the minimum torque needed in order to drive the robot. \\

    Mass of Robot = 510g \\
    Distance from Leg = 7.5 cm

    \begin{equation*}
      \begin{split}
        \therefore \text{Torque} &= \frac{510\left(7.5\right)}{2}\\
                                 &\approx 1913 \text{g}\cdot\text{cm}
      \end{split}
    \end{equation*}
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

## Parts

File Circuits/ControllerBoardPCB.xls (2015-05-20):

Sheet: BOM Report
Bill of Materials |  |  | Bill of Materials For PCB Document [ControllerBoardPCB.PcbDoc]
Source Data From: |  | ControllerBoardPCB.PcbDoc
Project: |  | EEE3061WDesignProject_ControllerBoard.PrjPCB
Variant: |  | None
Creation Date: | 2015-05-11 | 09:14:02 PM
Print Date: | 2015-05-11 | 21:41:37
Footprint | Comment | LibRef | Designator | Description | Quantity
CAPC500P450250X550_2.5mm | 100n | CAPR_220n_Radial_5mm | C1, C2, C3, C4 | Ceramic Capacitor | 4
CAPE10.0MM_Rad_10x14mm | 10uF | CAPE_470u_16V_THT | C5 | THT Capacitor | 1
CAPC500P450250X550_2.5mm | 1uF | CAPR_220n_Radial_5mm | C6, C7, C11 | Ceramic Capacitor | 3
CAPE10.0MM_Rad_10x14mm | 1uF | CAPE_470u_16V_THT | C8 | THT Capacitor | 1
CAPC500P450250X550_2.5mm | 10pF | CAPR_220n_Radial_5mm | C9, C10 | Ceramic Capacitor | 2
LED-1 | LED1 | LED1 | D1, D3, D4 | Normal LEDs | 3
USB_TypeB_Tyco | USB-B - UART | USB_TypeB | J1, J2 | Connector THT Type B USB connector | 2
HDR2X2 | POWER_HEADER | Header 2X2 | P1 | Header, 2-Pin, Dual row | 1
HDR2X5 | MCPUSBUART_HEADER | Header 5X2 | P2 | Header, 5-Pin, Dual row | 1
HDR1X24 | BREAKOUT_HEADER_LEFT | Header 24 | P3 | Header, 24-Pin | 1
HDR1X24 | BREAKOUT_HEADER_RIGHT | Header 24 | P4 | Header, 24-Pin | 1
HDR1X9 | GYRO_HEADER | Header 9 | P5 | Header, 9-Pin | 1
HDR1X2 | LIGHTSENSOR_HEADER | Header 2 | P6 | Header, 2-Pin | 1
HDR1X2 | V_EXT_CONNECTOR | Header 2 | P7 | MOLEX Header, 2-Pin | 1
HDR1X7 | POWERBOARD_HEADER | Header 7 | P8 | Header, 7-Pin | 1
RESTH_AXIAL-0.4 | Carbon Film | RES_1K_Axial_0.25W_5% | R1, R2, R4, R5, R7 | Normal Resistor | 5
TACT-SWITCH-TS1170 | SW_THT_PB_7.0mm | SW_THT_PB_7.0mm | S0, S1, S2 | 7mm Tactic Pushbutton | 3
STM32F051C6BreakoutBoard | STM32F051C6 Breakout Board | STM32F051C6Brk | U1 |  | 1
TO-92Wide | 3V3LinReg | VREG5V | U2 | MCP | 1
STM32F051C6_DbgrHdr | STM32F0DebuggerHdr | STM32F0DebuggerHdr | U3 |  | 1
TO-92Wide | LM35WidePin | LM35Big | U4 |  | 1
TO-92Wide | 5VLinReg | VREG5V | U5 | MCP | 1
8MHZOSC | 8MHz | XTAL | Y1 | Crystal Oscillator | 1
 |  |  |  |  | 38
Approved |  | Notes

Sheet: Project Information
Project Full Path | D:\ITDev\Projects\EEE3061WDesignProject\Circuits\EEE3061WDesignProject_ControllerBoard\EEE3061WDesignProject_ControllerBoard.PrjPCB
Project Filename | EEE3061WDesignProject_ControllerBoard.PrjPCB
Variant Name | None
Data-Source Filename | ControllerBoardPCB.PcbDoc
Data-Source Full Path | D:\ITDev\Projects\EEE3061WDesignProject\Circuits\EEE3061WDesignProject_ControllerBoard\ControllerBoardPCB.PcbDoc
Title | Bill of Materials For PCB Document [ControllerBoardPCB.PcbDoc]
Total Quantity | 38
Report Time | 09:14:02 PM
Report Date | 2015-05-11
Report Date & Tine | 2015-05-11 09:14:02 PM
Output Name | Bill of Materials
Output Type | BOM_PartType
Output Generator Name | BOM
Output Generator Description | Bill of Materials

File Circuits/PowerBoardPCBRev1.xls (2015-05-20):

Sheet: BOM Report
Bill of Materials |  |  | Bill of Materials For PCB Document [PowerBoardPCBRev1.PcbDoc]
Source Data From: |  | PowerBoardPCBRev1.PcbDoc
Project: |  | EEE3061WDesignProject_PowerBoard.PrjPcb
Variant: |  | None
Creation Date: | 2015-05-11 | 09:39:03 PM
Print Date: | 2015-05-11 | 21:41:37
Footprint | Comment | LibRef | Designator | Description | Quantity
CAPR5-4X5 | 0.1uF | Cap2 | C2, C3 | Capacitor | 2
HDR1X7 | POWERBOARDHEADER | Header 7 | P1 | Header, 7-Pin | 1
HDR1X2 | LEFT_MOTOR_CONNECTOR | Header 2 | P2 | MOLEX 'Header, 2-Pin | 1
HDR1X2 | RIGHT_MOTOR_CONNECTOR | Header 2 | P3 | MOLEX Header, 2-Pin | 1
HDR1X2 | V_EXT_CONNECTOR | Header 2 | P4 | MOLEX Header, 2-Pin | 1
HDR1X2 | BAT_CONNECTOR | Header 2 | P5 | MOLEX 'Header, 2-Pin | 1
DIP16 (NE) | L293DNE Motor Driver | L293DNE | U1 | H-Bridge DIP Socket (16-pin) | 1
 |  |  |  |  | 8
Approved |  | Notes

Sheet: Project Information
Project Full Path | D:\ITDev\Projects\EEE3061WDesignProject\Circuits\EEE3061WDesignProject_PowerBoard\EEE3061WDesignProject_PowerBoard.PrjPcb
Project Filename | EEE3061WDesignProject_PowerBoard.PrjPcb
Variant Name | None
Data-Source Filename | PowerBoardPCBRev1.PcbDoc
Data-Source Full Path | D:\ITDev\Projects\EEE3061WDesignProject\Circuits\EEE3061WDesignProject_PowerBoard\PowerBoardPCBRev1.PcbDoc
Title | Bill of Materials For PCB Document [PowerBoardPCBRev1.PcbDoc]
Total Quantity | 8
Report Time | 09:39:03 PM
Report Date | 2015-05-11
Report Date & Tine | 2015-05-11 09:39:03 PM
Output Name | Bill of Materials
Output Type | BOM_PartType
Output Generator Name | BOM
Output Generator Description | Bill of Materials

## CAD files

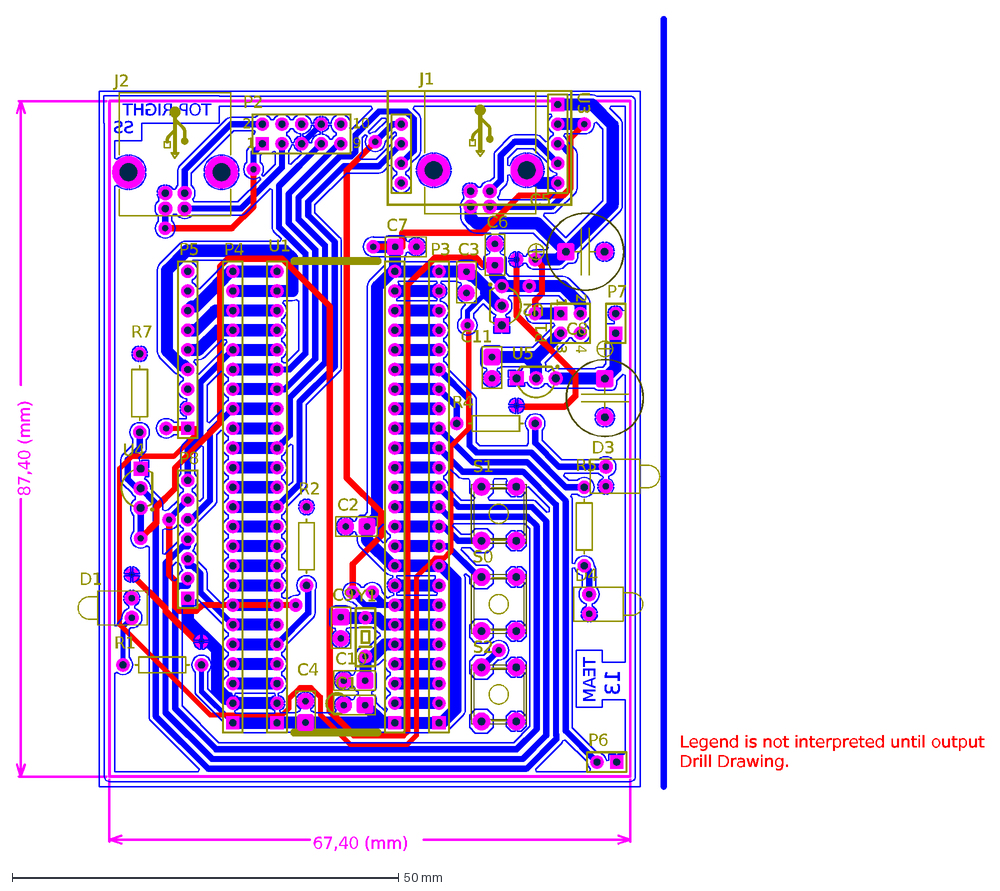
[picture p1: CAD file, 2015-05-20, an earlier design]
Circuits/EEE3061WDesignProject_ControllerBoard/ControllerBoardPCBMechanicalOut.DXF
Drill Drawing.
Legend is not interpreted until output
13
TEAM
SS
TOP-RIGHT
87,40 (mm)
67,40 (mm)
D4
R5
R4
U4
Y1
U5
U2
U1
S2
S1
S0
R7
R2
R1
P8
P7
P6
P5
P4
P3
2
1
9
10
P2
3
4
P1
J2
J1
D3
D1
C11
C10
C9
C8
C7
C6
C5
C4
C3
C2
C1
U3

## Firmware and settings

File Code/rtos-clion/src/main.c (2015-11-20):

/**
 ******************************************************************************
 * File Name          : main.c
 * Description        : Main program body
 ******************************************************************************
 *
 * COPYRIGHT(c) 2015 STMicroelectronics
 *
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
 ******************************************************************************
 */
/* Includes ------------------------------------------------------------------*/
#include "hal_lib.h"
#include "cmsis_os.h"
#include "userTasks_task.h"

// == Defines ==
#define TRUE          1
#define FALSE         0


// == Message Pools and Queues ==
// Global generic message and string message pool definitions
osPoolDef(genericMPool, GLOBAL_MESSAGE_MPOOL_SIZE, msg_genericMessage_t);
osPoolDef(strBufMPool, STRING_BUFFER_MPOOL_SIZE, msg_stringMessage_t);

// USART In Task String Queue
osMessageQDef(msgQUSARTIn, STRING_BUFFER_MPOOL_SIZE, msg_stringMessage_t);

// USART Out Task Message Queue
osMessageQDef(msgQUSARTOut, 2, msg_genericMessage_t);

// Boss Task Message Queue
osMessageQDef(msgQBoss, 5, msg_genericMessage_t);

// UserIO Task Message Queue
osMessageQDef(msgQUserIO, 4, msg_genericMessage_t);

/* USER CODE BEGIN PV */

/* USER CODE END PV */


/* USER CODE BEGIN PFP */

/* USER CODE END PFP */

int main(void) {
  /* MCU Configuration----------------------------------------------------------*/

  /* Reset of all peripherals, Initializes the Flash interface and the Systick. */
  HAL_Init();

  /* Configure the system clock */
  SystemClock_Config();

  /* Initialize all configured peripherals */
  MX_GPIO_Init();
  MX_DMA_Init();
//  MX_ADC_Init();
//  MX_SPI1_Init();
  MX_TIM1_Init();
  MX_TIM2_Init();
  MX_TIM6_Init();
  MX_TIM15_Init();
  MX_USART1_UART_Init();
  MX_USART2_UART_Init();

  // Beep da buzza
  int i = 0;
  int j = 0;
  while (j < 4) {
    HAL_GPIO_TogglePin(GPIOF, GPIO_PIN_6);
    for (i = 0; i < 300000; i++);
    j++;
  }

  HAL_TIM_PWM_Start(&htim2, TIM_CHANNEL_3);
  __HAL_TIM_SET_COMPARE(&htim2, TIM_CHANNEL_3, 100);

  // Initialise global flags
  globalFlags.states.commState = COMM_STATE_AUTO;
  globalFlags.states.wifiState = GEN_STATE_READY;
  globalFlags.procedures.wifiProcedures = WIFI_PROC_NONE;

  globalFlags.states.motorState = MTR_STATE_OFF;
  globalFlags.states.lineSensorState = LNS_STATE_OFF;

  globalFlags.motorData.leftMotorDir = MTR_DIR_DISABLED;
  globalFlags.motorData.leftMotorDir = MTR_DIR_DISABLED;
  globalFlags.motorData.leftMotorSpeed = 0;
  globalFlags.motorData.rightMotorSpeed = 0;
  globalFlags.motorData.controlState = MTR_CTRL_BANG_BANG;
  globalFlags.states.launcherState = LNCH_STATE_OFF;

  globalFlags.lineSensorData.linePos = LINE_POS_CENTER; // Initial condition is for the robot to be centered
  globalFlags.lineSensorData.boxPos = FALSE;
  globalFlags.lineSensorData.prevReedState = REED_DEFAULT;
  globalFlags.states.lightSensorState = LIGHT_STATE_OFF;

  /* Create the timer(s) */
  /* Definition and creation of ledTimer */
  osTimerDef(ledTimer, ledTimerCallback);
  ledTimerHandle = osTimerCreate(osTimer(ledTimer), osTimerOnce, NULL);

  /* Definition and creation of buzzerTimer */
  osTimerDef(buzzerTimer, buzzerTimerCallback);
  buzzerTimerHandle = osTimerCreate(osTimer(buzzerTimer), osTimerOnce, NULL);

  /* Create the thread(s) */
  osThreadDef(bossTask, StartBossTask, osPriorityNormal, 0, 128);
  bossTaskHandle = osThreadCreate(osThread(bossTask), NULL);

  osThreadDef(USARTInTask, StartUSARTInTask, osPriorityNormal, 0, 64);
  USARTInTaskHandle = osThreadCreate(osThread(USARTInTask), NULL);

  osThreadDef(USARTOutTask, StartUSARTOutTask, osPriorityNormal, 0, 128);
  USARTOutTaskHandle = osThreadCreate(osThread(USARTOutTask), NULL);

  osThreadDef(motorTask, StartMotorTask, osPriorityNormal, 0, 64);
  motorTaskHandle = osThreadCreate(osThread(motorTask), NULL);

  osThreadDef(sensorTask, StartSensorTask, osPriorityNormal, 0, 64);
  sensorTaskHandle = osThreadCreate(osThread(sensorTask), NULL);

  osThreadDef(userIOTask, StartUserIOTask, osPriorityNormal, 0, 128);
  userIOTaskHandle = osThreadCreate(osThread(userIOTask), NULL);

  /* USER CODE BEGIN RTOS_QUEUES */
  // Generic messaging and string message memory pools
  genericMPool = osPoolCreate(osPool(genericMPool));
  strBufMPool = osPoolCreate(osPool(strBufMPool));

  // USART In Task String Queue
  msgQUSARTIn = osMessageCreate(osMessageQ(msgQUSARTIn), NULL);

  // USART Out Task Queue
  msgQUSARTOut = osMessageCreate(osMessageQ(msgQUSARTOut), NULL);

  // Boss Task Queue
  msgQBoss = osMessageCreate(osMessageQ(msgQBoss), NULL);

  // UserIO Task Queue
  msgQUserIO = osMessageCreate(osMessageQ(msgQUserIO), NULL);

  /* Start scheduler */
  osKernelStart();

  /* We should never get here as control is now taken by the scheduler */

  /* Infinite loop */
  while (1) {
    __asm("nop");
  }
}

/* USART1 init function */
//void MX_USART1_UART_Init(void) {
//
//  huart1.Instance = USART1;
//  huart1.Init.BaudRate = 115200;
//  huart1.Init.WordLength = UART_WORDLENGTH_8B;
//  huart1.Init.StopBits = UART_STOPBITS_1;
//  huart1.Init.Parity = UART_PARITY_NONE;
//  huart1.Init.Mode = UART_MODE_TX_RX;
//  huart1.Init.HwFlowCtl = UART_HWCONTROL_NONE;
//  huart1.Init.OverSampling = UART_OVERSAMPLING_16;
//  huart1.Init.OneBitSampling = UART_ONEBIT_SAMPLING_DISABLED;
//  huart1.AdvancedInit.AdvFeatureInit = UART_ADVFEATURE_NO_INIT;
//  HAL_UART_Init(&huart1);
//
//}
//
///* USART2 init function */
//void MX_USART2_UART_Init(void) {
//
//  huart2.Instance = USART2;
//  huart2.Init.BaudRate = 115200;
//  huart2.Init.WordLength = UART_WORDLENGTH_8B;
//  huart2.Init.StopBits = UART_STOPBITS_1;
//  huart2.Init.Parity = UART_PARITY_NONE;
//  huart2.Init.Mode = UART_MODE_TX_RX;
//  huart2.Init.HwFlowCtl = UART_HWCONTROL_NONE;
//  huart2.Init.OverSampling = UART_OVERSAMPLING_16;
//  huart2.Init.OneBitSampling = UART_ONEBIT_SAMPLING_DISABLED;
//  huart2.AdvancedInit.AdvFeatureInit = UART_ADVFEATURE_NO_INIT;
//  HAL_UART_Init(&huart2);
//
//}


#ifdef USE_FULL_ASSERT

/**
 * @brief Reports the name of the source file and the source line number
 * where the assert_param error has occurred.
 * @param file: pointer to the source file name
 * @param line: assert_param error line source number
 * @retval None
 */
//void assert_failed(uint8_t* file, uint32_t line) {
//  /* USER CODE BEGIN 6 */
//  /* User can add his own implementation to report the file name and line number,
//   ex: printf("Wrong parameters value: file %s on line %d\r\n", file, line) */
//  /* USER CODE END 6 */
//
//}

#endif

/**
 * @}
 */

/**
 * @}
 */

/************************ (C) COPYRIGHT STMicroelectronics *****END OF FILE****/

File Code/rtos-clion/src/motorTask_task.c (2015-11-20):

/**
 * ============================================================================
 * File Name          : motorTask_task.c
 * Description        : motorTask Body
 * Author             : Sean Wood
 * ============================================================================
 */

// == Includes ==
#include "userTasks_task.h"

// == Definitions ==
#define FALSE 0
#define TRUE 1

#define MTR_SPEED_REACTION_PERIOD     1 // Period of changing PWM motor speed [+-ms]
#define MTR_UPDATE_PERIOD             20 // Interval between updating the motor control [+-ms]
#define LEFT_TRIM                     ((float)0) // Percentage trim of the left motor
#define RIGHT_TRIM                    ((float)0) // Percentage trim of the right motor

// For BANG BANG SMOOTH control
#define REDUCTION_STEP                10 // Percentage reduction to take off the speed of the motors for LEFT and RIGHT positions

// For SMOOTH control TODO Actually need to set SMOOTH control parameters
#define TRACKING_GAIN                 ((float)2) // Amount to decrease the motor speed by to achieve tracking
#define AUTO_SPEED                    ((float)100) // Percentage PWM to apply to motors when in auto drive mode
#define MIN_TRACKING_SPEED            ((float)0) // Minimum speed a motor can reach during tracking
#define SETTLE_SPEED                  ((float)0.25) // Amount to decrease the cumulative error when line is in center
#define MAX_ERROR_COUNT               100000 // Maximum accumulation

// == Private Function Declarations ==
static void interpretSignal(osEvent *signalEvent);
static void controlMotors(void);
static void stopMotors(void);
static void disableMotors(void);
static void enableMotors(void);
static void setMotors(float leftSpeed, float rightSpeed);

static void disableLauncher(void);
static void enableLauncher(void);
static void launch(void);
static void terminateLaunch(void);

static void setLF(float speed);
static void setLR(float speed);
static void setRF(float speed);
static void setRR(float speed);
static void setLaunchF(float speed);
static void setLaunchR(float speed);

// == Function Definitions ==

/**
 * @brief motorTask
 * @param argument
 */
void StartMotorTask(void const * argument) {
  globalFlags.motorData.leftMotorDir = MTR_DIR_DISABLED;
  globalFlags.motorData.leftMotorDir = MTR_DIR_DISABLED;
  globalFlags.motorData.leftMotorSpeed = 0;
  globalFlags.motorData.rightMotorSpeed = 0;

  static uint8_t step = 0;

  disableMotors();

  /* Infinite loop */
  for (;;) {
    globalFlags.generalData.motorTaskStackHWM = uxTaskGetStackHighWaterMark(motorTaskHandle);

    // Wait for the signal forever, unless the motors are running
    osEvent signalEvent = osSignalWait(0,
        ((globalFlags.states.motorState != MTR_STATE_RUNNING) && (globalFlags.states.launcherState == LNCH_STATE_OFF)) ? (1000) : 0);

    if (signalEvent.status == osEventSignal) {
      interpretSignal(&signalEvent);
    }

    // If we are tracking the line
    if ((globalFlags.states.lineSensorState == LNS_STATE_ON)
        && globalFlags.states.motorState == MTR_STATE_RUNNING) {
      controlMotors();
    }

    // Check to see if the box line has been passed
    if (globalFlags.lineSensorData.boxPos || step != 0) {

      // Update data
      globalFlags.states.lineSensorState = LNS_STATE_OFF;
      globalFlags.states.motorState = MTR_STATE_OFF;

      osThreadSetPriority(motorTaskHandle, osPriorityAboveNormal);

      switch (step) {
      case 0:
        // First re-orient the robot
        setMotors(100, 0);
        osDelay(500);
        setMotors(0, 0);
        step = 1;
        break;
      case 1:
        // Make sure the robot is a bit more in the box
        setMotors(100, 100);
        osDelay(1250);
        step = 2;
        break;
      case 2:
        // Then continue to drive forward until the edge of the box is reached (until the sensors both trigger)
        setMotors(0, 0);
        enableLauncher();
        launch();
        step = 3;
        osThreadSetPriority(motorTaskHandle, osPriorityNormal);

//        if (HAL_GPIO_ReadPin(GPIOB, GPIO_PIN_4) || HAL_GPIO_ReadPin(GPIOB, GPIO_PIN_3)) {
//          // Stop and launch after 1s
//          setMotors(0, 0);
//          osDelay(1000);
//          enableLauncher();
//          launch();
//          step = 3;
//          osThreadSetPriority(motorTaskHandle, osPriorityNormal);
//        } else {
//          setMotors(100, 100);
//        }
        break;
      default:
        break;
      }
    }

    osDelay(MTR_UPDATE_PERIOD);
  }
}

static void controlMotors(void) {
  // Grab the current line position as picked up by the sensors
  linePos_t linePositionCurrent = globalFlags.lineSensorData.linePos;
  static float errorCount = 0; // How many times have we updated the speed but have not achieved line tracking


  // Limit the accumulation
  if (errorCount < 80) {
    errorCount += 0.1;
  }

  // CONTROL SEQUENCE
  switch (linePositionCurrent) {
  case LINE_POS_LEFT: {
    // If control is BANG BANG, LEFT position should not do anything
    if (globalFlags.motorData.controlState == MTR_CTRL_BANG_BANG) {
      setMotors(AUTO_SPEED + LEFT_TRIM, AUTO_SPEED + RIGHT_TRIM);
    } else if (globalFlags.motorData.controlState == MTR_CTRL_BANG_BANG_SMOOTH) {
      // Else, if in BANG BANG SMOOTH mode, reduce the speed by a set step
      setMotors(AUTO_SPEED + LEFT_TRIM - REDUCTION_STEP,
      AUTO_SPEED + RIGHT_TRIM);
    } else if (globalFlags.motorData.controlState == MTR_CTRL_SMOOTH) {
      // Else, if in SMOOTH control, do the calcs

      // Adjust the error counter
      // If it is not zero, decrease until zero is reached
      if (errorCount > 0) {
        errorCount -= SETTLE_SPEED;
      }

      // Calculate the adjustment
      float newSpeed = globalFlags.motorData.leftMotorSpeed - (errorCount * TRACKING_GAIN);

      // Set the new speed of the motors, taking into account the minimum allowable speed
      setMotors((newSpeed < MIN_TRACKING_SPEED) ? (MIN_TRACKING_SPEED) : (newSpeed), globalFlags.motorData.rightMotorSpeed);
    }
    break;
  }
  case LINE_POS_RIGHT: {
    // If control is BANG BANG, LEFT position should not do anything
    if (globalFlags.motorData.controlState == MTR_CTRL_BANG_BANG) {
      setMotors(AUTO_SPEED + LEFT_TRIM, AUTO_SPEED + RIGHT_TRIM);
    } else if (globalFlags.motorData.controlState == MTR_CTRL_BANG_BANG_SMOOTH) {
      // Else, if in BANG BANG SMOOTH mode, reduce the speed by a set step
      setMotors(AUTO_SPEED + LEFT_TRIM,
      AUTO_SPEED + RIGHT_TRIM - REDUCTION_STEP);
    } else if (globalFlags.motorData.controlState == MTR_CTRL_SMOOTH) {
      // Else, if in SMOOTH control, do the calcs

      // Adjust the error counter
      // If it is not zero, decrease until zero is reached
      if (errorCount > 0) {
        errorCount -= SETTLE_SPEED;
      }

      // Calculate the adjustment
      float newSpeed = globalFlags.motorData.rightMotorSpeed - (errorCount * TRACKING_GAIN);
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

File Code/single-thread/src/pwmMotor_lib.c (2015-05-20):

/**
 * ============================================================================
 * EEE3061W Design Project
 * ============================================================================
 *
 * @file      | pwmMotor_lib.c
 * @brief     | Motor Control Library (PWM)
 * @pre       | mtr
 * @authors   | Team 13
 *
 * This library is used for control of two motors in both directions via PWM
 * to a quad-h-bridge (L293DNE). NOTE: Protection against shoot-through is
 * critical!
 *
 * Traces can be output using trace_puts() for strings or trace_printf() for
 * formatted strings
 *
 * ============================================================================
 */

// == Includes ==
#include "pwmMotor_lib.h"

// == Defines ==


// == Global Variables ==


// == Helper Declarations ==
void setRF(uint8_t dutyCycle);
void setLF(uint8_t dutyCycle);
void setRR(uint8_t dutyCycle);
void setLR(uint8_t dutyCycle);


/**
 * @brief Initialise the timers for motor control
 * @param None
 * @retval None
 */

void mtr_motorTimInit(void) {
  // Left Motor Forward: PA11 - TIM1_CH4
  // Left Motor Reverse: PA3 - TIM15_CH2
  // Left Motor Enable: PB6
  // Right Motor Forward: PA8 - TIM1_CH1
  // Right Motor Reverse: PA2 - TIM15_CH1
  // Right Motor Enable: PB7

  mtr_motorENState = MTR_DISABLED;
  mtr_motorOpState = MTR_STOPPED;
  mtr_motorLibraryState = MTR_LIB_DISABLED;

  // Gather the RCC clocks for the timers we need
  RCC_AHBPeriphClockCmd(RCC_AHBPeriph_GPIOA, ENABLE);
  RCC_AHBPeriphClockCmd(RCC_AHBPeriph_GPIOB, ENABLE);
  RCC_APB2PeriphClockCmd(RCC_APB2Periph_TIM1, ENABLE);
  RCC_APB2PeriphClockCmd(RCC_APB2Periph_TIM15, ENABLE);

  // Setup TIM7 as controlTimer to be used for PID control
  RCC_APB1PeriphClockCmd(RCC_APB1Periph_TIM7, ENABLE); // Enable the RCC clock for TIM7
  TIM_TimeBaseInitTypeDef controlTimerBaseInitStructure;

  TIM_Cmd(TIM7, DISABLE);
  TIM_DeInit(TIM7); // Reset the timer to default values
  TIM_TimeBaseStructInit(&controlTimerBaseInitStructure);

  controlTimerBaseInitStructure.TIM_CounterMode = TIM_CounterMode_Up;
  controlTimerBaseInitStructure.TIM_Period = 0xFFFF; // Set the ARR to 100              | This gives us a max time of 65.535 sec
  controlTimerBaseInitStructure.TIM_Prescaler = 0xBB80; // Set the prescaler to 48000   | and a time-base of 1ms per LSB
  TIM_TimeBaseInit(TIM7, &controlTimerBaseInitStructure);

  TIM_DeInit(TIM1);
  TIM_DeInit(TIM15);

  //Initialise the Enable pins
  GPIO_InitTypeDef mtr_GPIOENInitStruct;
  mtr_GPIOENInitStruct.GPIO_Pin = GPIO_Pin_6 | GPIO_Pin_7;
  mtr_GPIOENInitStruct.GPIO_Mode = GPIO_Mode_OUT;
  mtr_GPIOENInitStruct.GPIO_OType = GPIO_OType_PP;
  mtr_GPIOENInitStruct.GPIO_PuPd = GPIO_PuPd_UP;
  mtr_GPIOENInitStruct.GPIO_Speed = GPIO_Speed_Level_3;
  GPIO_Init(GPIOB, &mtr_GPIOENInitStruct);

  // Double check they are low
  GPIO_ResetBits(GPIOB, GPIO_Pin_6);
  GPIO_ResetBits(GPIOB, GPIO_Pin_7);

  // Initialise the PWM GPIO pins
  GPIO_InitTypeDef mtr_GPIOPWMFInitStruct;
  mtr_GPIOPWMFInitStruct.GPIO_Mode = GPIO_Mode_AF; // Alternate Function for timer PWM output
  mtr_GPIOPWMFInitStruct.GPIO_OType = GPIO_OType_PP;
  mtr_GPIOPWMFInitStruct.GPIO_Pin = GPIO_Pin_2 | GPIO_Pin_3 | GPIO_Pin_8 | GPIO_Pin_11;
  mtr_GPIOPWMFInitStruct.GPIO_Speed = GPIO_Speed_Level_3;
  mtr_GPIOPWMFInitStruct.GPIO_PuPd = GPIO_PuPd_UP;
  GPIO_Init(GPIOA, &mtr_GPIOPWMFInitStruct);
  GPIO_PinAFConfig(GPIOA, GPIO_PinSource2, GPIO_AF_0);
  GPIO_PinAFConfig(GPIOA, GPIO_PinSource3, GPIO_AF_0);
  GPIO_PinAFConfig(GPIOA, GPIO_PinSource8, GPIO_AF_2);
  GPIO_PinAFConfig(GPIOA, GPIO_PinSource11, GPIO_AF_2);

  // Initialise the PWM for both TIM1 and TIM15
  TIM_TimeBaseInitTypeDef mtr_TIMTimebaseInitStruct;
  TIM_TimeBaseStructInit(&mtr_TIMTimebaseInitStruct); // Get the structure ready for init
  mtr_TIMTimebaseInitStruct.TIM_CounterMode = TIM_CounterMode_Up;
  mtr_TIMTimebaseInitStruct.TIM_Prescaler = 48; // Will give 1Mhz base
  mtr_TIMTimebaseInitStruct.TIM_Period = 1000; // 1KHz PWM frequency
  TIM_TimeBaseInit(TIM1, &mtr_TIMTimebaseInitStruct);
  TIM_TimeBaseInit(TIM15, &mtr_TIMTimebaseInitStruct);

  TIM_OCInitTypeDef mtr_TIMOCInitStruct;
  TIM_OCStructInit(&mtr_TIMOCInitStruct); // These are here to set everything to default to make the param assertion happy
  mtr_TIMOCInitStruct.TIM_OCIdleState = TIM_OCIdleState_Reset;
  mtr_TIMOCInitStruct.TIM_OCMode = TIM_OCMode_PWM1; // With upcounting, this gives positive leading pulse and directly proportional duty cycle
  mtr_TIMOCInitStruct.TIM_OutputState = TIM_OutputState_Enable; // Enable the output?

  TIM_OC1Init(TIM1, &mtr_TIMOCInitStruct); // TIM1 Channel 1 output compare init
  TIM_OC4Init(TIM1, &mtr_TIMOCInitStruct); // TIM1 Channel 4 output compare init
  TIM_OC1Init(TIM15, &mtr_TIMOCInitStruct); // TIM15 Channel 1 output compare init
  TIM_OC2Init(TIM15, &mtr_TIMOCInitStruct); // TIM15 Channel 2 output compare init

  // Enable the capture compare on both TIM1 and TIM15
  TIM_CtrlPWMOutputs(TIM1, ENABLE);
  TIM_CCxCmd(TIM1, TIM_Channel_1, TIM_CCx_Enable);
  TIM_CCxCmd(TIM1, TIM_Channel_4, TIM_CCx_Enable);

  TIM_CtrlPWMOutputs(TIM15, ENABLE);
  TIM_CCxCmd(TIM15, TIM_Channel_1, TIM_CCx_Enable);
  TIM_CCxCmd(TIM15, TIM_Channel_2, TIM_CCx_Enable);

  // Make sure the motors are off
  mtr_stop();

}


/**
 * @brief Set/reset the enable GPIOs for the chosen side of the H-Bridge
 * @param None
 * @retval None
 */

void mtr_leftEnable(void) {
  GPIO_SetBits(GPIOB, GPIO_Pin_6);
  mtr_motorENState = MTR_ENABLED;
}

void mtr_leftDisable(void) {
  GPIO_ResetBits(GPIOB, GPIO_Pin_6);
}

void mtr_rightEnable(void) {
  GPIO_SetBits(GPIOB, GPIO_Pin_7);
  mtr_motorENState = MTR_ENABLED;

}

void mtr_rightDisable(void) {
  GPIO_ResetBits(GPIOB, GPIO_Pin_7);
}

/**
 * @brief Bring the motors to the speed specified and cater for large changes in speed
 * @param direction: Which direction both motors should be driven
 *        leftSpeed: Speed of the left motor
 *        rightSpeed: Speed of the right motor
 * @retval None
 */
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

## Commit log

2015-03-06 Revert "Testing branch checkout"
    This reverts commit 197154d9e7c8f1f2ce9d906ef9f4600bdece0c02.
    [main.c]
2015-03-12 Circuit: Light Sensor PCB initial commit :arrow_down:
    [EEE3061WDesignProject_LEDLightSensor.PrjPcb, LightSensorSchematic.SchDoc]
2015-03-16 Light Sensor initial commit
    [EEE3061WDesignProject_LEDLightSensor.PrjPcb, LightSensorSchematic.SchDoc]
2015-03-17 LightSensor: Update schematic (rev2)
    [LightSensorSchematic.SchDoc]
2015-03-17 File restructure and Light Sensor Report initial commit
2015-03-17 Light Sensor: Fix sensing and updated circuit (rev3)
    [EEE3061WDesignProject_LEDLightSensor.PrjPcb, LightSensorSchematic.SchDoc]
2015-03-20 LightSensor: Completed schematic (rev4)
    [EEE3061WDesignProject_LEDLightSensor.PrjPcb, LightSensorSchematic.SchDoc, LightSensorSchematic.sch]
2015-04-02 LightSensor: V2.0 initial commit (rev5)
    Only green sensing is needed now, also changed digital output technology
    to P-Channel Enhancement Mode MOSFET
    [EEE3061WDesignProject_LEDLightSensorV2.0.PrjPcb, LightSensorSchematic.SchDoc]
2015-04-05 LightSensor: Saved a near loss of schematic!
    [EEE3061WDesignProject_LEDLightSensor.PrjPcb, LightSensorSchematic.SchDoc]
2015-04-05 LightSensor: Fixed missing resistor
    [EEE3061WDesignProject_LEDLightSensor.PrjPcb, LightSensorSchematic.SchDoc]
2015-04-05 ControllerBoard: Initial commit
    [ControllerBoardSchematic.SchDoc, EEE3061WDesignProject_ControllerBoard.PrjPCB, LightSensorSchematic.SchDoc]
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2015-04-11 Code: Implement gyro
    Still need to fix assert_param() errors
    [main.c, spiGyro_lib.c]
2015-04-11 Code: Fixed param issues
    Still need to get the SPI communications working
    [main.c, spiGyro_lib.c]
2015-04-12 Code: Still bug fixing
    [main.c, spiGyro_lib.c]
2015-04-13 Code: Corrected 2s comp conversion
    [spiGyro_lib.c]
2015-04-13 Code: Changed CS pin
    Changed the CS pin for the Gyro since both the EEPROM and Gyro sit on
    the same SPI bus, and were using the same CS line - still doesn't work
    though
    [spiGyro_lib.c]
2015-04-20 Revert "Code: Added some shit"
    This reverts commit b6dd91587d48ffd37ccc12b3356cac43dab8a5db.
    [main.c]
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2015-04-21 Code: Added TempSense_lib
    Something's wrong! Veeeery wrong! :( :(
    [main.c]
2015-04-22 Code: Fixed conflicts and refactor issues
    [adcTempSense_lib.c, main.c, spiGyro_lib.c]
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2015-04-24 Code: Corrected order of register setup
    [spiGyro_lib.c]
2015-04-25 PCB: Created STM32F0 Breakout Board component
    [ControllerBoardSchematic.SchDoc, EEE3061WDesignProject_ControllerBoard.PrjPCB, STM32F051C6Breakout.PcbLib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]
2015-04-26 Code: Started implementing calibration
    Just setup the timer to keep time of our data poll time step for
    integration purposes. STM running at 48MHz and is set to the external
    osc for max precision!
2015-04-26 Code: Continued implementation of calibration
    ...including starting up the gyro (as a method)
2015-04-26 Code: Calibration method complete
    Still need to get integration in place and cleanup!!
2015-04-27 Code: Angle output working
    Still need to test accuracy and temperature drift, also need to
    implement USB tracing
    [main.c, spiGyro_lib.c]
2015-04-28 Code: Serial Communication support and implemented zeroing via SW0
    All outgoing serial communication can be done via printf() - still needs
    to be tested
2015-04-29 Code: Improve zeroing functionality, PCB: Continue
    Started putting in standard parts for the Controller Board
    [ControllerBoardSchematic.SchDoc]
2015-05-01 Code: Completed and presented Yaw Sensor
    Few updates to the ControllerBoard schematic as well.
    [ControllerBoardSchematic.SchDoc, STM32F051C6Breakout.SchLib]
2015-05-03 PCB: Osc, headers and more
    [ControllerBoardSchematic.SchDoc]
2015-05-04 PCB: Added in a header or two
    [ControllerBoardSchematic.SchDoc]
2015-05-04 PCB: Change power config to support any voltage input
    [ControllerBoardSchematic.SchDoc]
2015-05-05 PCB: Added L293DNE, PowerBoard and continued ControllerBoard
    [ControllerBoardSchematic.SchDoc, EEE3061WDesignProject_PowerBoard.PrjPcb, L293DNE.PcbLib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]
2015-05-06 PCB: PowerBoard complete
    [ControllerBoardSchematic.SchDoc, EEE3061WDesignProject_PowerBoard.PrjPcb, PowerBoardPCB.PcbDoc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]
2015-05-08 PCB: ControllerBoard and PowerBoard finalised
    Still need to double check
    [ControllerBoardPCB.PcbDoc, ControllerBoardSchematic.SchDoc, EEE3061WDesignProject_ControllerBoard.PrjPCB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]
2015-05-11 PCB: Revised boards, outputs, BOMs and cable summary
    [ControllerBoardPCB.PcbDoc, ControllerBoardPCBMechanicalOut.DXF, EEE3061WDesignProject_ControllerBoard.PrjPCB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]
2015-05-13 Code: Jig the libraries for the new board
    [ControllerBoardPCB.PcbDoc, ControllerBoardPCB.xls, EEE3061WDesignProject_ControllerBoard.PrjPCB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]
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2015-05-16 Code: Most of full execution done
    [ControllerBoardPCB.PcbDoc, PowerBoardPCBRev1.PcbDoc, PowerBoardSchematic.SchDoc]
2015-05-18 Code: Finished control, led strips and light sensor
    Still needs testing
    [ControllerBoardPCB.PcbDoc, PowerBoardPCBRev1.PcbDoc]
2015-08-04 FInished line presence sensor schematic
    [EEE3061WDesignProject_LineSensor.PrjPcb, LineSensorSchematic.SchDoc]
2015-08-15 Circuits: Schematics complete
    [ControllerBoardCMPV2.PcbLib, ControllerBoardCMPV2.SchLib, ControllerBoardV2Schematic.SchDoc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]
2015-08-15 Corrected LED placement on sensor board
    [LineSensorBoardSchematic.SchDoc]
2015-08-16 Sensor board routing complete
    [LineSensorBoardPCB.PcbDoc]
2015-08-16 Sensor board touched up and power board routed
    [LineSensorBoardPCB.PcbDoc, PowerBoardPCB.PcbDoc, PowerBoardSchematicV2.SchDoc]
2015-08-18 All PCBs at final draft level
    [ControllerBoardV2PCB.PcbDoc, ControllerBoardV2Schematic.SchDoc, EEE3061WDesignProjectLineSensorBoard.PrjPcb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]
2015-08-20 Finished all PCBs
    [ControllerBoardV2PCB.PcbDoc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]
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2015-09-05 Created threads for motors and line sensor
    Also added associated enum values for messages, task data structs etc
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2015-09-06 Added UserIO task, implemented software timers
    UserIO task for buttons, buzzer and indicator LED
    [bossTask_task.c, hal_lib.c, main.c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]
2015-09-06 Button handling, fixed major memory leak, implemented signals on two tasks
    [bossTask_task.c, lineSensorTask_task.c, main.c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]
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2015-09-08 Revert "Started light sensor functionality"
    This reverts commit a2114c0673020d664c1175430ab9c3820c343a50.
    [hal_lib.c, lineSensorTask_task.c, main.c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]
2015-09-08 Revert "Revert "Started light sensor functionality""
    This reverts commit 9c8f088e7c37d0792faefe99995d3bf2a6120345.
    [hal_lib.c, lineSensorTask_task.c, main.c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]
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2015-09-29 Add ability to change control method on the fly, fix a few other things
    [EEE3061WDesignProject_ControllerBoard.PrjPCB, EEE3061WDesignProject_PowerBoard.PrjPcb, PowerBoardSchematic.SchDoc]
2015-10-04 Cleanup, add auto wifi init and telemetry
    [EEE3061WDesignProject_ControllerBoard.PrjPCB, EEE3061WDesignProject_PowerBoard.PrjPcb, PowerBoardPCBRev1.PcbDoc]
2015-10-07 Finish line sensor (working), add more remote capabilities
    [EEE3061WDesignProject_ControllerBoard.PrjPCB, EEE3061WDesignProject_PowerBoard.PrjPcb]
2015-10-12 Create new report and bring deliverable project to a close
    [EEE3061WDesignProjectLineSensorBoard.PrjPcb, EEE3061WDesignProjectLineSensorModule.PrjPcb, EEE3061WDesignProject_ControllerBoardV2.PrjPcb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]
